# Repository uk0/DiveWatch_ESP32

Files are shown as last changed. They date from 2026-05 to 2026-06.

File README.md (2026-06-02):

<p align="center">
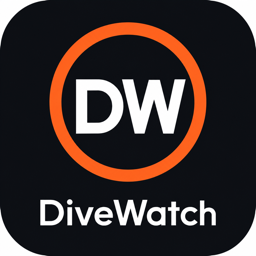
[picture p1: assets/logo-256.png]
DiveWatch
  
</p>

<h1 align="center">DiveWatch</h1>

<p align="center">
  <b>DIY 开源潜水电脑</b> · ESP32-S3 + ST7789 + MS5837<br/>
  完整工程：<b>固件 + 3D 外壳 + 安卓 App</b>
</p>

<p align="center">
  <a href="README.md">中文</a> ·
  <a href="README.en.md">English</a> ·
  <a href="LICENSE">MIT License</a>
</p>

<p align="center">
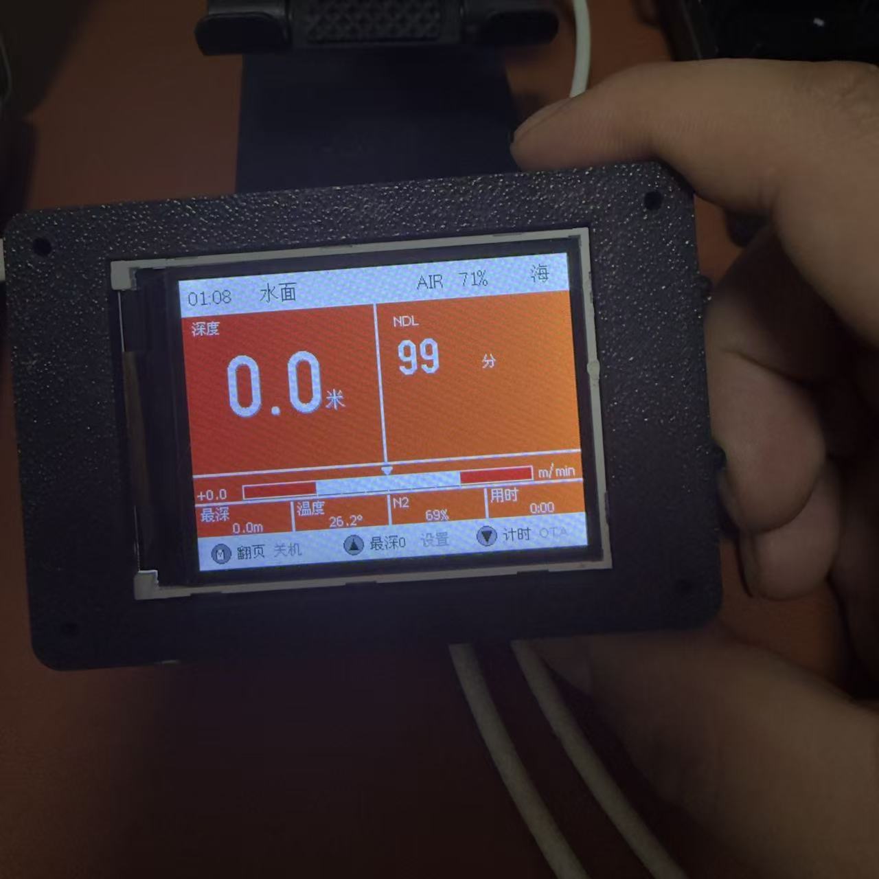
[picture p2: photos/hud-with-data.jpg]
HUD 主页
  
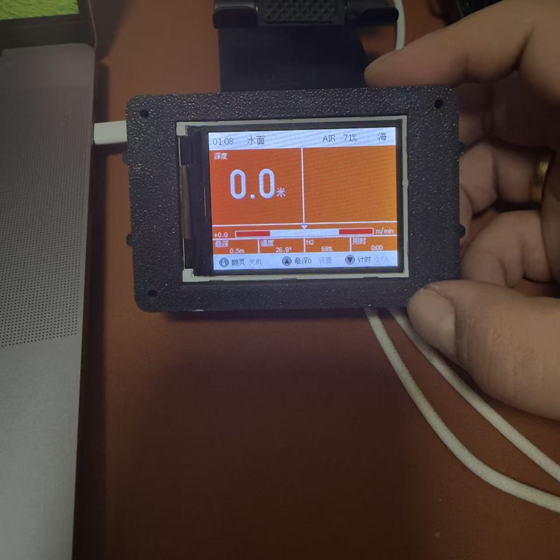
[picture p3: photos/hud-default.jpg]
HUD 默认
  
</p>
<p align="center">
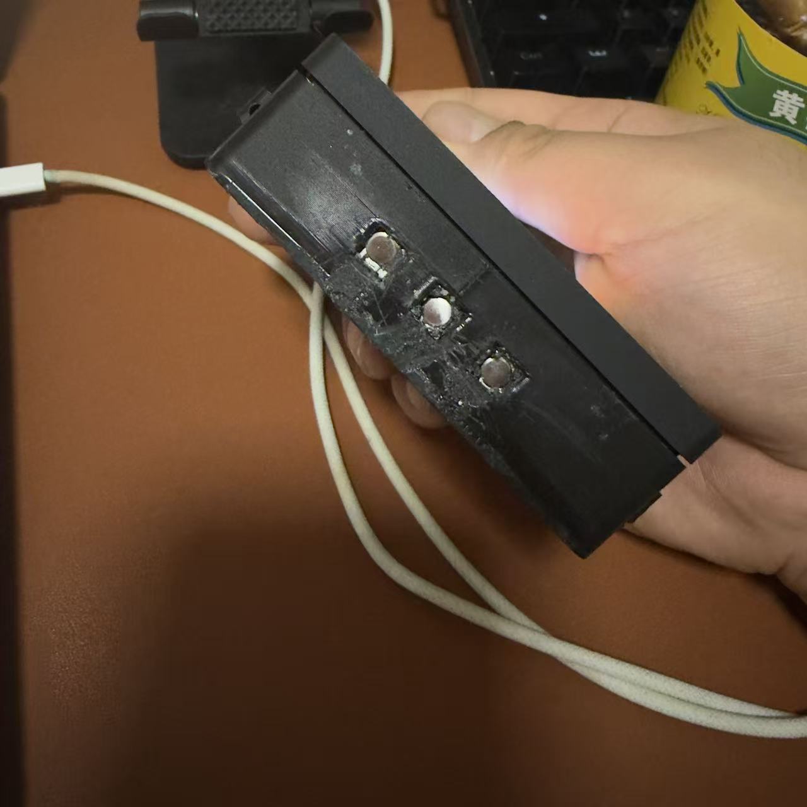
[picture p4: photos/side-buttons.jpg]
3 按钮侧
  
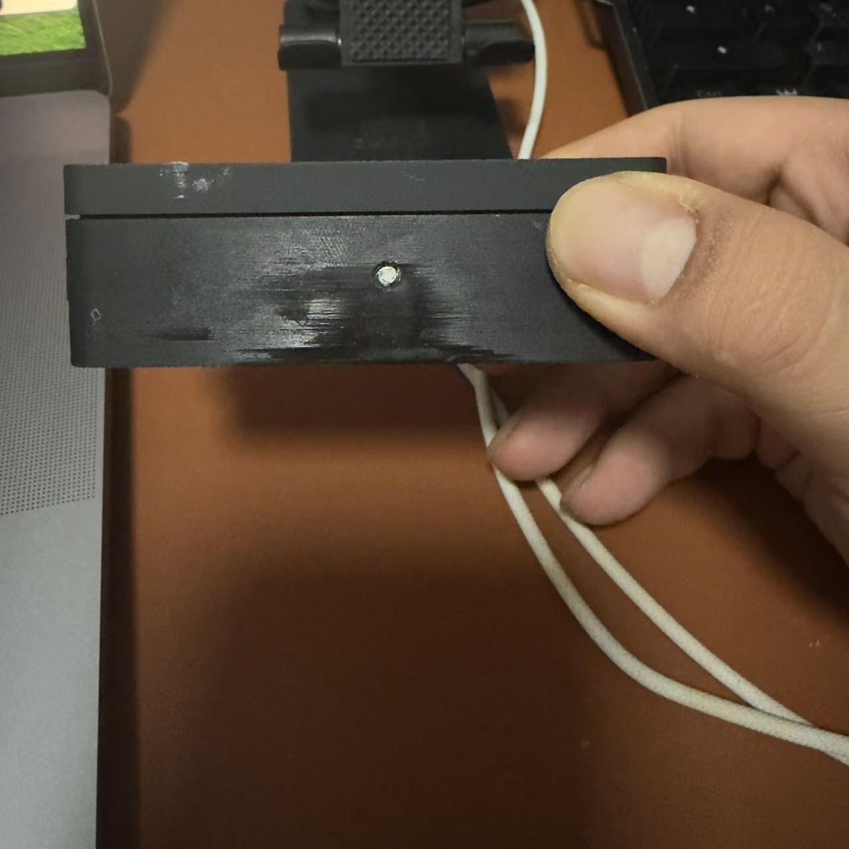
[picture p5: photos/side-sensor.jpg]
压力传感器侧
  
</p>

---

> ⚠ **本项目仅供学习娱乐，未经任何潜水认证机构认证。下水必须携带认证潜水电脑或潜水表作为主设备。**

## 特性

- **Garmin Descent X50i 风格 HUD**：11 个数据页面 + 全屏告警 + 进出水画面
- **ZHL-16C Bühlmann 减压算法**：16 组织室 + 海拔补偿 + 保守因子
- **安全停留 AOW 标准**：2.5-6m 窗口，累积计时，30s 抖动容差
- **OTA 刷不死**：BLE 配 WiFi → WiFi OTA 双 slot 自动回滚
- **超低功耗待机**：Light Sleep ~5mA / Deep Sleep ~10μA
- **完整 3D 打印外壳**：树脂底壳 + 树脂顶盖 + TPU 软套
- **Android App**：扁平化 BLE 配 WiFi + WiFi OTA + 潜水记录本地存储

## 仓库结构

```
watcher/
├── arduino/DiveWatch_v4/    # 固件 (~3400 行 .ino + BLE OTA 模块)
├── case_v5/                 # 3D 外壳源码 (build123d Python)
├── case/                    # 3D 外壳产物 (.step / .stl / .3mf)
├── android_app/             # 安卓 App (Capacitor 7 + Vanilla JS)
├── assets/                  # 图片资源
├── PINOUT.md                # ESP32-S3 引脚映射
├── HARDWARE.md              # BOM + 接线图
└── README.md / README.en.md
```

## 硬件

| 件 | 型号 | 接线 |
|---|---|---|
| 主控 | ESP32-S3-Nano (4 MB Flash / 8 MB PSRAM) | — |
| 显示屏 | ST7789 2.4" SPI 240×320 | CS=21 / DC=18 / RST=17 / MOSI=38 / SCK=48 / BL=8 |
| 压力传感器 | MS5837-30BA | I²C SDA=11 / SCL=12 (地址 0x76) |
| 按键 | 3 × 6×6 SMT | MODE=6 / UP=7 / DOWN=10 |
| 蜂鸣器 | 9042 + S8050 NPN | GPIO 5 经 1kΩ → 三极管基极 |
| 电池监测 | 2:1 分压 (推荐 10K+10K) | ADC A0 = GPIO 1 |
| 无线充电 | Qi 5V/1A 接收 + TP4056 | 详见 [HARDWARE.md](HARDWARE.md) |

完整引脚清单 → [PINOUT.md](PINOUT.md) · BOM/接线图 → [HARDWARE.md](HARDWARE.md)

## 快速开始

### 1. 固件烧录

```bash
cd arduino
arduino-cli compile --upload \
  -p /dev/cu.usbmodem2101 \
  --fqbn esp32:esp32:esp32s3:PartitionScheme=min_spiffs,CDCOnBoot=cdc \
  DiveWatch_v4
```

第一次烧入需要 BOOT+RST 进下载模式。后续可通过 OTA 升级（无需 USB）。

### 2. 3D 打印外壳

```bash
cd case_v5
pip install build123d
python3 case_v5.py
# 输出: ../case/{top_cover, bottom_case, tpu_bumper}.{step, stl, 3mf}
```

| 件 | 工艺 | 推荐材料 |
|---|---|---|
| `bottom_case` | 树脂 (SLA/DLP) | 高韧性灰树脂, 层高 0.05mm |
| `top_cover` | 树脂 (SLA/DLP) | 同上，屏幕窗精度要求高 |
| `tpu_bumper`  | FDM | TPU 95A，0.2mm 层高，30mm/s |

### 3. Android App 编译

```bash
cd android_app
npm install
npm run build           # esbuild bundle
npx cap sync android
JAVA_HOME=/Library/Java/JavaVirtualMachines/temurin-25.jdk/Contents/Home \
  ./android/gradlew -p ./android assembleDebug
# APK 输出: android/app/build/outputs/apk/debug/app-debug.apk
```

## OTA 升级流程

**第一次配 WiFi (BLE)**

1. 设备进 OTA 模式：设置菜单 → 第 14 项「进入 OTA」
2. 手机 App → 工具页 → 扫描连接 `DiveWatch-OTA`
3. WiFi 配置卡填 SSID + 密码 → 点连接
4. 设备屏幕显示分配的 IP

**后续升级 (WiFi)**

1. 设备进 OTA 模式（自动连之前保存的 WiFi）
2. App 工具页 → 固件 OTA → 选 .bin 文件 → 推送
3. 进度条 100% 设备自动重启
4. **5 秒内未启动成功，自动回滚到上一版本**

完整 OTA 说明 → [arduino/DiveWatch_v4/OTA_GUIDE.md](arduino/DiveWatch_v4/OTA_GUIDE.md)

## 屏幕布局

```
┌─顶栏: 时间│DIVE/水面│AIR│电量│海/淡────┐  黑底白字
├─[2px 黑]──────────────────────────────┤
│ 深度        │  NDL / 安停 / 上升过快  │  橙底
│ XX.X 米     │  XX (大字)              │
│ ▼最深 X.Xm │  状态/动作               │
├─[2px 黑]──────────────────────────────┤
│ +X.X ◀━━━●━━━▶ m/min                  │  上升速度
├─[2px 黑]──────────────────────────────┤
│最深│温度│N2│用时                       │  数据条
├─[2px 黑]──────────────────────────────┤
│ ⓂM翻页│ ▼最深0│ ▲计时                 │  黑底白字按键提示
└─────────────────────────────────────────┘
```

## 11 个页面

| 页 | 内容 |
|---|---|
| HUD | 主页面 (深度/NDL/安停/速度/温度/用时/N2/最深) |
| PROFILE | 潜水深度曲线 |
| TISSUE | 16 组织室饱和度条 |
| N2 | 当前 N2 负载详情 |
| PLAN | 下潜计划 (NDL 表) |
| AIR | 气瓶 SPG + SAC + Air Time |
| TEMP | 温度趋势 |
| BAT | 电池电压/百分比/曲线 |
| LASTDIVE  | 上次潜水摘要 |
| LOG | 潜水日志列表 |
| STATS | 累计统计 |

## 文档

- [PINOUT.md](PINOUT.md) — ESP32-S3 引脚完整映射
- [HARDWARE.md](HARDWARE.md) — BOM + 接线图 + 装配顺序
- [arduino/DiveWatch_v4/OTA_GUIDE.md](arduino/DiveWatch_v4/OTA_GUIDE.md) — OTA 防砖架构
- [android_app/README.md](android_app/README.md) — App 开发说明
- [CHANGELOG.md](CHANGELOG.md) — 版本历史
- [CONTRIBUTING.md](CONTRIBUTING.md) — 贡献指南

## 许可证

MIT — 见 [LICENSE](LICENSE)。

## 致谢

- [build123d](https://github.com/gumyr/build123d) — Python CAD
- [u8g2](https://github.com/olikraus/u8g2) — 字体引擎
- [NimBLE-Arduino](https://github.com/h2zero/NimBLE-Arduino) — 轻量 BLE 栈
- [Adafruit GFX / ST7789](https://github.com/adafruit/Adafruit-GFX-Library) — 显示驱动
- [Capacitor](https://capacitorjs.com/) — Web → 原生 App 框架
- [Chart.js](https://www.chartjs.org/) — 图表
- Bühlmann ZHL-16C 减压算法参考 [Shearwater](https://www.shearwater.com/) 公开文档

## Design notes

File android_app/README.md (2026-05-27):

# DiveWatch Android App

Capacitor 7 + Vanilla JS + Chart.js + IndexedDB

## 功能

- **主页**: 大字电池 + 深度/温度/WiFi/IP 四宫格 + 深度实时曲线 + 累计统计
- **日志**: 历次潜水柱状图 + 列表（自动按 60s 静止判定潜水结束并落库）
- **工具**: BLE 扫描连接 / WiFi 配置 / WiFi OTA 推送 / 实时日志

## 存储

- 设置项 (WiFi SSID): `@capacitor/preferences`
- 潜水记录: IndexedDB (database `divewatch`, store `dives`)

## BLE

走 `@capacitor-community/bluetooth-le` 原生插件，Android 12+ 自动请求 BLUETOOTH_SCAN/CONNECT 权限。
浏览器开发时回退 Web Bluetooth。

## 构建

```bash
cd android_app
npm install
npm run build        # esbuild bundle www/app.js → www/bundle.js
npm run sync         # cap sync android (拷贝 www → android/app/src/main/assets/public)

# build APK (debug)
JAVA_HOME=/Library/Java/JavaVirtualMachines/temurin-25.jdk/Contents/Home \
  ./android/gradlew -p ./android assembleDebug

# 出 APK 路径
ls android/app/build/outputs/apk/debug/app-debug.apk
```

## Logo

由 gpt-image-2 生成 (`icon.png`)，已切成 5 档 mipmap 放入 `android/app/src/main/res/mipmap-*`.

## 安装到手机

1. 用 USB 把 `app-debug.apk` 拷到手机 (或 adb install)
2. 手机开 "未知来源安装" 权限
3. 双击 APK 安装
4. 打开 App → 工具页 → 扫描连接 (DiveWatch-OTA)

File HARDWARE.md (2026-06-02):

# DiveWatch 硬件清单

## BOM (Bill of Materials)

### 主板

| 件 | 型号 | 数量 | 参考价 (¥) | 备注 |
|---|---|---|---|---|
| 主控板 | ESP32-S3-Nano | 1 | 25-40 | 4MB Flash / 8MB PSRAM, Arduino Nano 形态 |
| 显示屏 | ST7789 2.4" SPI 240×320 | 1 | 25-35 | 必须带 FPC 排线 |
| 压力传感器 | MS5837-30BA | 1 | 40-60 | I²C 0x76, 30 bar 量程 |
| 按键 | 6×6 SMT 微动开关 | 3 | 0.5/颗 | 6.2mm 帽 |
| 蜂鸣器 | 9042 无源 | 1 | 2 | 5V 驱动 |
| NPN 三极管 | S8050 | 1 | 0.2 | 蜂鸣器开关 |
| 限流电阻 | 1kΩ 0805 | 1 | 0.1 | 基极电流限制 |

### 电池 & 充电

| 件 | 型号 | 数量 | 参考价 (¥) | 备注 |
|---|---|---|---|---|
| 锂电池 | 503040 600mAh Li-Po | 1 | 8-15 | 单体 3.7V |
| 充电管理 | TP4056 USB-C 带保护板 | 1 | 3-5 | 1A 充电, DW01 过冲过放保护 |
| 无线充接收 | Qi 5V/1A 模块带 43mm 线圈 | 1 | 10-15 | 直径需匹配 45mm 凹槽 |
| 电池分压电阻 | 10kΩ × 2 (0805) | 2 | 0.1 | ADC 友好, 漏电 210μA |
| 充电底座 | 任意 Qi 5W 充电板 | 1 | 30-80 | Anker / 小米 / 绿联 |

### 外壳 & 配件

| 件 | 规格 | 数量 | 参考价 (¥) | 备注 |
|---|---|---|---|---|
| 树脂打印 (底壳) | bottom_case.3mf 21mm | 1 | 15-30 | 8K 树脂打印推荐 |
| 树脂打印 (顶盖) | top_cover.3mf 7mm | 1 | 10-20 | 同上 |
| TPU 软套 | tpu_bumper.3mf | 1 | 5-10 | TPU 95A FDM 自打 |
| M2 自攻螺丝 | 8mm 长 4 颗 | 4 | 0.2 | 装顶盖 |
| 弹簧棒 | 24mm × Φ2.5 | 2 | 1 | 接表带 |
| 表带 | 24mm 宽硅胶 | 1 | 10-30 | 任意运动手表表带 |
| 防水 O 圈 | 自定义剪 | 1 | 1 | 密封槽 (可选, 已有 lip 设计) |

**总成本估算：¥150-300** (含一套 3D 打印外壳)

## 接线图

```
                     ┌───────────────┐
                     │  ESP32-S3-Nano │
                     │               │
   ST7789 ─SPI─────►│ GPIO 21 (CS)  │
                    │ GPIO 18 (DC)  │
                    │ GPIO 17 (RST) │
                    │ GPIO 38 (MOSI)│
                    │ GPIO 48 (SCK) │
                    │ GPIO  8 (BL)  │
                    │               │
   MS5837 ─I²C─────►│ GPIO 11 (SDA) │
                    │ GPIO 12 (SCL) │
                    │               │
   按键 ────────────►│ GPIO  6 (MODE)│
                    │ GPIO  7 (UP)  │
                    │ GPIO 10 (DOWN)│
                    │               │
   蜂鸣器 ─1kΩ─B─NPN─│ GPIO  5       │
                    │               │
   电池+ ──[10K]────►│ GPIO  1 (ADC) │
            │       │               │
           [10K]    │ 3V3 / GND     │
            │       └───────────────┘
           GND
                    ┌───────────────┐
   Qi RX 5V+ ──────►│  TP4056 IN+   │
                    │  TP4056 IN-   │── GND
   ┌────────────────│  TP4056 BAT+  │
   │                │  TP4056 BAT-  │── GND
   │
   ▼ 电池 +
   Li-Po 600mAh
   ▼ 电池 -
   GND
```

## 引脚总览

完整引脚映射见 [PINOUT.md](PINOUT.md)。

| 类别 | 引脚 |
|---|---|
| 已用 | 1, 5, 6, 7, 8, 10, 11, 12, 17, 18, 21, 38, 48 |
| 空闲 | 2, 3, 4, 9, 13, 14, 43, 44, 47 |
| 占用 (USB/Flash/PSRAM) | 0, 15, 16, 19, 20, 26-37, 39-42, 45, 46 |

## 装配顺序

1. **PCB 焊接** — 主控、屏幕排线、按键、蜂鸣器电路、电池分压
2. **底壳准备** — 检查内腔尺寸，按键孔通畅
3. **无线充线圈** — 双面胶固定到底壳内腔顶 (Qi 线圈凹槽)
4. **电池** — 放入内腔底部
5. **TP4056** — 焊好后用 Kapton 胶带固定到电池上方
6. **主控板** — 屏幕从顶盖底部装入（4 凸起卡 PCB），FPC 折弯进 PCB 沉槽
7. **盖上顶盖** — 对齐密封槽 + 凸起
8. **4 颗 M2 螺丝** — 拧紧固定
9. **TPU 套** — 拉伸套入，按键孔/传感器孔/屏幕窗/表带通道全对齐
10. **接表带** — 弹簧棒压入耳片孔

## 防水建议

- 密封 lip + 槽设计已提供 IP55 级 (浅水）
- 真要下深水：
  - 密封槽涂硅胶脂 (Permatex Dielectric Grease)
  - 增加丁腈 O 圈
  - 螺丝头部涂厌氧胶
  - **务必做压力测试**：泡 30 分钟 -10m 深度等效气压（约 2 bar）

⚠ DIY 防水极不可靠，**严禁下任何超出泳池深度的水**。

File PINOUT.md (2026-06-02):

# DiveWatch v4 引脚总表 (ESP32-S3-Nano)

## 一、开发板信息

| 项目 | 值 |
|---|---|
| 主控芯片 | ESP32-S3 (双核 240MHz, 4MB Flash, 8MB PSRAM) |
| 开发板名称 | ESP32-S3-Nano (Arduino Nano 形态) |
| 板载接口 | USB-C (兼容 OTG + CDC) |
| 工作电压 | 3.3V |
| 板载稳压 | 5V → 3.3V LDO |
| 引脚数 | 30 (左右各 15) |
| 通讯接口 | UART × 1, I²C × 1, SPI × 1, USB-CDC × 1 |
| ADC | 12-bit, 多通道 (GPIO 1-10 可作 ADC) |
| Arduino-ESP32 核心 | 3.3.8 |
| FQBN | `esp32:esp32:esp32s3:PartitionScheme=min_spiffs,CDCOnBoot=cdc` |
| 分区方案 | min_spiffs (1.94MB × 2 OTA slot + 128KB SPIFFS) |
| Sketch 大小 | ~1.84 MB (占 93% 单 slot) |
| RAM 使用 | ~80 KB |
| 烧录波特率 | 921600 baud |

### CPU 频率档位 (代码 130-131 行)

| 状态 | 频率 | 估计电流 |
|---|---|---|
| 活动工作 (CPU_FREQ_ACTIVE) | 240 MHz | ~80 mA |
| 屏保 (CPU_FREQ_IDLE) | 80 MHz | ~40 mA |
| Light Sleep | ~ | ~5-10 mA |
| Deep Sleep | ~ | ~10 μA |

---

## 二、引脚分配总表

### 显示器 ST7789 2.4" SPI (HSPI 总线, 40 MHz)

| 信号 | GPIO | 板上丝印 | 用途 |
|---|---|---|---|
| **TFT_CS** | **GPIO 21** | D10 | SPI 片选 |
| **TFT_DC** | **GPIO 18** | D9  | Data/Command 切换 |
| **TFT_RST** | **GPIO 17** | D8  | 硬复位 |
| **TFT_MOSI** | **GPIO 38** | D11 | SPI 主出从入 (HSPI MOSI) |
| **TFT_SCK** | **GPIO 48** | D13 | SPI 时钟 (HSPI SCK) |
| (TFT_MISO) | — | — | 未连接 (显示器单向只写) |
| **BLK 背光** | 3V3 | — | 接 3V3 永亮 (软件无控制) |
| VCC | 3V3 | — | 显示器电源 |
| GND | GND | — | 共地 |

### MS5837-30BA 压力传感器 (I²C, 400 kHz)

| 信号 | GPIO | 板上丝印 | 用途 |
|---|---|---|---|
| **I2C_SDA** | **GPIO 11** | D2 | I²C 数据 |
| **I2C_SCL** | **GPIO 12** | D3 | I²C 时钟 |
| VIN | 3V3 | — | 传感器电源 |
| GND | GND | — | 共地 |
| 100nF 电容 | VIN↔GND | — | 退耦 (必须) |

**I²C 地址**: `0x76` (MS5837-30BA 固定地址)

### 按钮 (内部上拉, 按下短接 GND)

| 信号 | GPIO | 板上丝印 | 用途 |
|---|---|---|---|
| **BTN_MODE_PIN** | **GPIO 6** | D4 | 模式键 (翻页 / 长按关机) |
| **BTN_UP_PIN** | **GPIO 7** | D5 | 上键 (最深0 / 设置增) |
| **BTN_DOWN_PIN** | **GPIO 10** | D7 | 下键 (计时重置 / 设置减) |

**按键时序**: 30ms 防抖 + 1200ms 长按阈值 + 5s 关机阈值。

### 蜂鸣器 (有源, 经 S8050 NPN 驱动)

| 信号 | GPIO | 板上丝印 | 用途 |
|---|---|---|---|
| **BUZZER_PIN** | **GPIO 5** | D1 | NPN 基极 (1kΩ 限流) |

**驱动电路**: GPIO 5 → 1kΩ → S8050 Base; Emitter→GND; Collector→蜂鸣器−; 蜂鸣器+ → 3V3。

### 电池电压检测 (ADC 分压)

| 信号 | GPIO | 板上丝印 | 用途 |
|---|---|---|---|
| **BAT_ADC_PIN** | **GPIO 1** | A0 | 电池电压 ADC (2:1 分压) |

**分压电路**: 电池 + → 4.7kΩ → ADC 引脚 → 4.7kΩ → GND。  
**软件校准系数** `g_batDivider = 2.10` (适配 ±5% 电阻容差, 可在设置菜单微调 1.80-2.30)。

### USB-C (板载, 自动复用)

| 信号 | 用途 |
|---|---|
| USB-C 5V | 充电 + 通讯 (经 TP4056 充电保护板) |
| USB D+/D− | USB CDC 串口 (CDCOnBoot=cdc 启用) |

---

## 三、未使用引脚 (可扩展)

下列引脚目前空闲，可用于未来扩展（磁力计/加速度计/外置 Flash 等）：

| GPIO | 板上丝印 | 推荐用途 |
|---|---|---|
| GPIO 2 | A1 | 备用 ADC |
| GPIO 3 | A2 | 备用 ADC / 触摸 |
| GPIO 4 | A3 | 备用 ADC / 触摸 |
| GPIO 8 | A4 | 备用 (磁力计 INT) |
| GPIO 9 | A5 | 备用 |
| GPIO 13 | A6 | 备用 |
| GPIO 14 | D6 | 备用 |
| GPIO 15 | — | 备用 |
| GPIO 16 | — | 备用 |
| GPIO 33-37 | — | PSRAM 用 (不能动) |
| GPIO 39-42 | — | 备用 |
| GPIO 45-47 | — | 备用 |

⚠️ **不能使用**：GPIO 19/20 (USB D+/D−), GPIO 0 (Boot 控制), GPIO 22-32 (内部 Flash/PSRAM)

---

## 四、外围模块 BOM

| 模块 | 型号 | 数量 | 接线引脚 |
|---|---|---|---|
| 主控板 | ESP32-S3-Nano (R8, 8MB Flash + 8MB PSRAM) | 1 | — |
| 显示模块 | ST7789 2.4" SPI 240×320 | 1 | GPIO 17/18/21/38/48 + 3V3/GND |
| 压力传感器 | MS5837-30BA | 1 | GPIO 11/12 + 3V3/GND |
| 蜂鸣器 | 9042 有源蜂鸣器 (3-5V) | 1 | GPIO 5 (经 NPN) |
| NPN 三极管 | S8050 | 1 | 驱动蜂鸣器 |
| 限流电阻 | 1 kΩ (棕黑红金) | 1 | S8050 Base |
| 分压电阻 | 4.7 kΩ ×2 | 2 | ADC 分压 |
| 充电板 | TP4056 + DW01 + FS8205 (带保护) | 1 | USB-C + 电池 |
| 锂电池 | 3.7V 850 mAh (50×30×5 mm) | 1 | TP4056 B+ / B− |
| 退耦电容 | 100 nF (104) | 1 | MS5837 VIN-GND |
| 按钮 | 4 脚扁平微动按钮 | 3 | GPIO 6/7/10 |

---

## 五、走线建议 (飞线方案)

```
ESP32-S3-Nano        外设
─────────────────────────────────
D2 (GPIO11) ──I2C── SDA  MS5837
D3 (GPIO12) ──I2C── SCL  MS5837
3V3        ──────── VIN  MS5837 (+ 100nF 退耦)
GND        ──────── GND  MS5837

D8 (GPIO17) ─SPI─── RST  ST7789
D9 (GPIO18) ─SPI─── DC   ST7789
D10(GPIO21) ─SPI─── CS   ST7789
D11(GPIO38) ─SPI─── SDA  ST7789 (MOSI)
D13(GPIO48) ─SPI─── SCL  ST7789 (SCK)
3V3        ──────── VCC + BLK
GND        ──────── GND

D1 (GPIO5)  ──1kΩ── Base S8050
GND        ──────── Emitter
                    Collector ── 蜂鸣器(−)
3V3        ──────── 蜂鸣器(+)

D4 (GPIO6)  ──────── 按钮 MODE ─── GND
D5 (GPIO7)  ──────── 按钮 UP   ─── GND
D7 (GPIO10) ──────── 按钮 DOWN ─── GND

A0 (GPIO1)  ─4.7k── 电池 BAT+
                   ─4.7k── GND  (分压中点)

TP4056:
  IN+/IN−  ──── USB-C
  B+/B−    ──── 电池
  OUT+     ──── ESP32-S3 5V (经板载稳压 → 3V3)
  OUT−     ──── GND
```

---

## 六、烧录命令

```bash
# 编译
arduino-cli compile \
  --fqbn esp32:esp32:esp32s3:PartitionScheme=huge_app,CDCOnBoot=cdc \
  arduino/DiveWatch_v4

# 烧录
arduino-cli upload \
  -p /dev/cu.usbmodem2101 \
  --fqbn esp32:esp32:esp32s3:PartitionScheme=huge_app,CDCOnBoot=cdc \
  arduino/DiveWatch_v4
```

⚠️ 首次烧录前需手动进入下载模式：**按住 BOOT + 短按 RST → 松开 RST → 松开 BOOT**。  
`CDCOnBoot=cdc` 启用后第二次起 esptool 自动 reset 进入下载模式。

---

## 七、功耗估算

| 场景 | 电流 | 850mAh 续航 |
|---|---|---|
| HUD 主屏运行 (240MHz, 屏幕亮) | ~120 mA | ~7 h |
| 屏保 + Light Sleep (80MHz, 屏幕仍亮) | ~50 mA | ~17 h |
| 屏保 + Light Sleep + 屏幕关 (理论) | ~10 mA | ~85 h |
| Deep Sleep (RTC 唤醒) | ~10 μA | 数年 |

⚠️ 当前 BLK 接 3V3 永亮，背光占主要功耗（~25 mA）。如需省电，可把 BLK 改接 GPIO 做 PWM 调光（**PINOUT 升级方案**）。

---

## 八、引脚定义索引 (代码位置)

| 定义 | 文件 | 行号 |
|---|---|---|
| TFT_CS / DC / RST / MOSI / SCK | DiveWatch_v4.ino | 38-42 |
| I2C_SDA / I2C_SCL | DiveWatch_v4.ino | 106-107 |
| BUZZER_PIN | DiveWatch_v4.ino | 108 |
| BTN_MODE_PIN / BTN_UP_PIN / BTN_DOWN_PIN | DiveWatch_v4.ino | 109-111 |
| BAT_ADC_PIN | DiveWatch_v4.ino | 112 |
| WIFI_SSID / NTP 服务器 | DiveWatch_v4.ino | 73-77 |
| CPU 频率档位 | DiveWatch_v4.ino | 129-130 |

如改动接线，只需改这些 `#define`，无需动其他代码。

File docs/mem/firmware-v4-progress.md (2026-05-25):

# DiveWatch v4 固件开发进度快照 (2026-05-26)

## 当前固件版本
- 主目录: `arduino/DiveWatch_v4/`
- 文件:
  - `DiveWatch_v4.ino` (主固件, ~3400 行)
  - `ota_ble.ino` (BLE + WiFi OTA 模块)
  - `partitions.csv` (已删, 改用预设 `min_spiffs`)
  - `OTA_GUIDE.md` (OTA 使用文档)
  - `ota_web_client.html` (浏览器 BLE 配 WiFi 工具)

## 编译/烧录命令
```bash
# 编译 + USB 烧录
arduino-cli compile --upload \
  -p /dev/cu.usbmodem2101 \
  --fqbn esp32:esp32:esp32s3:PartitionScheme=min_spiffs,CDCOnBoot=cdc \
  DiveWatch_v4

# WiFi OTA (浏览器访问 http://<IP>/ 上传 .bin)
# 在 OTA 模式下设备显示 IP, 浏览器打开即可
```

## 硬件
- ESP32-S3-Nano (4MB Flash, 8MB PSRAM)
- ST7789 2.4 寸 SPI 屏 240x320 (HSPI 40MHz)
- MS5837-30BA 压力传感器 (I2C 0x76)
- 3 按钮 (GPIO 6/7/10) + 蜂鸣器 (GPIO 5) + 电池 ADC (GPIO 1)
- 4MB Flash 限制下 sketch ~1.84MB, min_spiffs 双 OTA slot 1.96MB 各

## 已实现功能
1. **Garmin Descent X50i 风格 UI**: 11 个页面 (HUD/PROFILE/TISSUE/N2/PLAN/AIR/TEMP/BAT/LASTDIVE/LOG/STATS) + 设置 + 时间编辑 + 屏保 + 全屏告警
2. **ZHL-16C Bühlmann 减压算法** + 16 组织室 + 海拔补偿 + 保守因子
3. **安全停留 AOW 标准** (2.5-6m 窗口, 累积计时, 30s 抖动容差)
4. **TTS + Ceiling 计算** (上升到水面时间, 含减压停留)
5. **气瓶 SPG**: 初始 bar / 瓶容 / SAC / Air Time 估算
6. **进出水画面**: 进入 1.5s "GO!", 退出 5s 总结
7. **WiFi NTP 校时** (用户填 SSID/PSK)
8. **Light sleep + Deep sleep** 省电
9. **配色**: 橙底 + 黑文字 + 红警告 (Shearwater 水下哲学)
10. **OTA 防砖**: BLE 配 WiFi → WiFi OTA / HTTP Web 上传 / 双 slot 自动回滚

## OTA 防砖架构
- **双 OTA 分区** (min_spiffs: 1.94MB×2 + 128KB SPIFFS)
- **触发方式** (4 种):
  - 设置菜单 → 第 14 项「进入 OTA」→ UP/DOWN 确认
  - 长按 UP 5 秒 / DOWN 5 秒
  - 串口发 `OTA\n`
  - 开机时按 UP **或** DOWN (救援模式, 跳过所有初始化)
- **退出 OTA**: MODE 双击 (400ms 内 2 次) / 长按 1 秒
- **OTA 通道**:
  - HTTP Web (端口 80, 浏览器访问 `http://<IP>/` 上传)
  - ArduinoOTA (端口 3232, `espota.py` 命令行)
  - BLE 配 WiFi (NimBLE-Arduino 2.5.0)
- **自动回滚**: 新固件 5s 内未 `mark_valid` 下次重启回上一 slot

## 屏幕刷新优化
- HUD 渲染 100ms (10Hz)
- 缓存层: time/HH:MM, DIVE 状态, 用时秒, 电量, 海/淡, 大字深度, NDL, 安停, 速度条, 数据条 4 项, AIR (静态)
- 上升速度阈值 0.5 m/min (避免传感器噪声触发重画)

## 已知问题/待办
- 4MB Flash 限制下 sketch 91% 占用, 加新功能需先瘦身
- ArduinoOTA UDP invitation 在某些路由器下不稳, 推荐用 HTTP Web 上传
- 字体合并副作用: wqy13→wqy12 (字号小 1px), logisoso26→24

## 关键文件大小
- DiveWatch_v4.ino: ~3400 行 / ~120 KB
- ota_ble.ino: ~250 行
- 编译产物 .bin: ~1.84 MB

## Git 历史 (最近)
```
7aa8a60 HUD 屏闪深度优化: 用时缓存(1Hz)+AIR静态(0Hz)+上升阈值放宽(0.5m/min)
b840627 OTA + 屏幕刷新优化
24d6283 OTA: 加 HTTP Web 80 端口
ca6908e v4 OTA: BLE 广播显式 name+UUID, TX +9dBm; 长按 MODE 3s 退出 OTA
0b55918 v4 OTA: 加设置菜单第 14 项 '进入 OTA' 避免按键冲突
1d654d3 v4 OTA 双 slot 启用: NimBLE + 字体合并 (sketch 2.06→1.80MB)
```

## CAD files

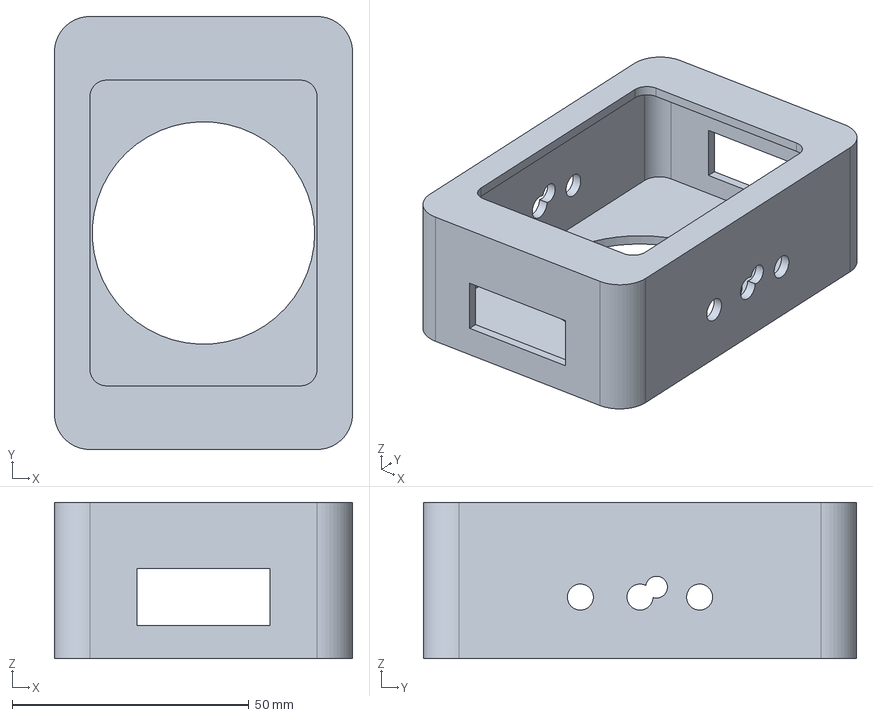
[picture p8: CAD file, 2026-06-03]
case/tpu_bumper.step
63.0 x 91.5 x 33.0 mm

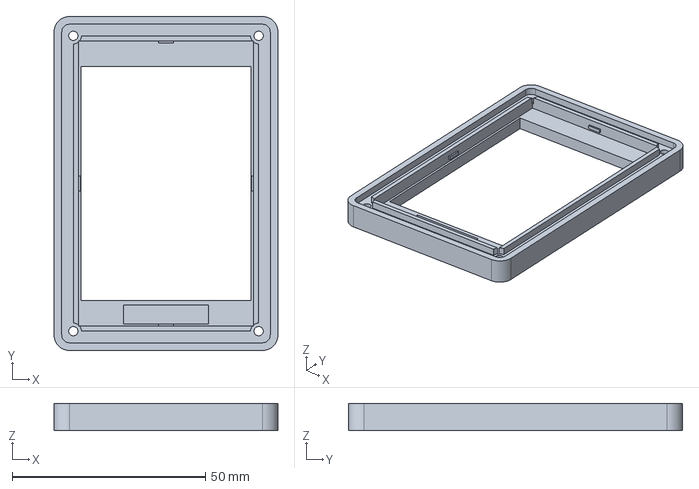
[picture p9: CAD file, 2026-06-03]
case/top_cover.step
58.0 x 86.5 x 7.00 mm

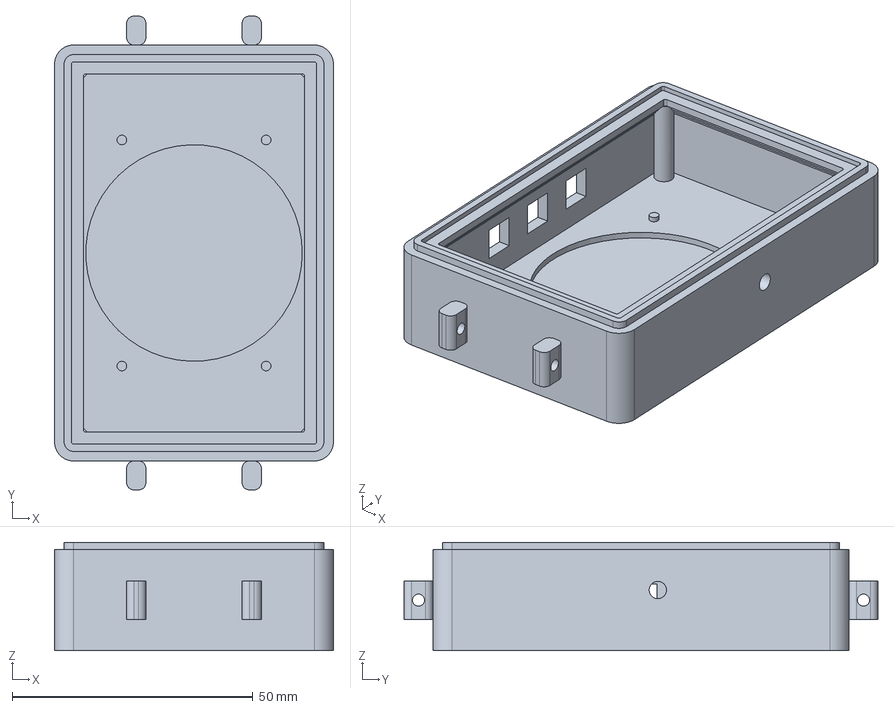
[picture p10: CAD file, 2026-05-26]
case/bottom_case.step
58.0 x 98.5 x 22.5 mm

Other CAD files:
case/bottom_case.3mf
case/bottom_case.stl
case/top_cover.3mf
case/top_cover.stl
case/tpu_bumper.3mf
case/tpu_bumper.stl

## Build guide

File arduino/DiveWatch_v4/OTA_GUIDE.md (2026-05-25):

# 刷不死方案: BLE 配 WiFi + WiFi OTA

## 架构

```
   ┌──────────┐      BLE (慢, 仅控制)        ┌────────────────┐
   │ 用户手机/ │ ─── SSID/PSK + CMD ────→    │  DiveWatch     │
   │ 浏览器    │                              │  ESP32-S3      │
   └──────────┘                              └────────────────┘
        ↓                                            ↓
        │                                       WiFi STA 模式
        │                                            ↓
        │                                     ArduinoOTA :3232
        │                                            ↑
        ↓ 通过家里 WiFi 路由器                       │
   ┌──────────┐    WiFi (快 ~500 KB/s)       ┌─────┴────────┐
   │ PC / 笔记本│ ────── 推 .bin 固件 ──→     │  ESP32-S3    │
   └──────────┘                              └──────────────┘
```

**核心思路**：BLE 只做"配网+控制"（数据量小），WiFi 做"高速传输"（固件 1.9MB / WiFi 4 秒，BLE 200 秒）。

## 三种触发方式

| 方式 | 操作 | 适用 |
|---|---|---|
| **A** | 长按 MODE+UP 3 秒 | 主固件正常, 想升级 |
| **B** | 开机时按 UP+DOWN (救援) | 主固件 brick |
| **C** | 串口/代码 `otaScheduleNextBoot()` | 远程/脚本触发 |

## 一次性首烧 (后面不再需要 USB)

```bash
# 编译 (使用自定义双 OTA 分区)
cd arduino
arduino-cli compile \
  --fqbn esp32:esp32:esp32s3:PartitionScheme=custom,CDCOnBoot=cdc \
  --build-property "build.custom_partitions=partitions" \
  DiveWatch_v4

# 按 BOOT+RST 进下载模式, 然后:
arduino-cli upload \
  -p /dev/cu.usbmodem2101 \
  --fqbn esp32:esp32:esp32s3:PartitionScheme=custom,CDCOnBoot=cdc \
  --build-property "build.custom_partitions=partitions" \
  DiveWatch_v4
```

## 日常 OTA 升级流程

### 第一次配 WiFi (BLE)

1. 设备进 OTA 模式 (任一触发方式)
2. 屏幕显示 "OTA 模式 / BLE 配 WiFi 中..."
3. 手机/电脑用 Chrome/Edge 打开 `ota_web_client.html`
4. 点 "连接 DiveWatch-OTA"
5. 填 WiFi 名 + 密码 → 点 "连接 WiFi"
6. 设备屏幕显示 "OTA 已就绪 / IP: 192.168.x.x"
7. 凭据自动保存到 NVS

### 后续 OTA (WiFi 自动连)

1. 设备进 OTA 模式 (任一方式)
2. **自动用保存的 WiFi 凭据连接** (无需 BLE)
3. 屏幕显示 "OTA 已就绪 / IP: ..."
4. 用 PC 推固件:

```bash
# 用 arduino-cli (推荐, 自动找 .bin)
arduino-cli upload -p 192.168.1.50 \
  --fqbn esp32:esp32:esp32s3:PartitionScheme=custom,CDCOnBoot=cdc \
  --build-property "build.custom_partitions=partitions" \
  DiveWatch_v4

# 或 espota.py 直接推 .bin
python3 ~/Library/Arduino15/packages/esp32/hardware/esp32/3.3.8/tools/espota.py \
  -i 192.168.1.50 -p 3232 \
  -f ~/Library/Caches/arduino/sketches/*/DiveWatch_v4.ino.bin

# 或 Arduino IDE: 工具 → 端口 → 选 DiveWatch (192.168.1.50)
```

5. 进度条到 100% 设备自动重启，新固件运行
6. **5 秒内成功启动则标记 valid，否则下次重启自动回滚**

## BLE GATT 协议

| Char | UUID | 操作 | 内容 |
|---|---|---|---|
| Service | `1d14d6ee-fd63-4fa1-bfa4-8f47b42119f0` | - | OTA 服务 |
| SSID | `f7bf3564-fb6d-4e53-88a4-5e37e0326063` | Write | UTF-8 字符串 |
| PSK | `984227f3-34fc-4045-a5d0-2c581f81a153` | Write | UTF-8 字符串 |
| CMD | `0c533cef-d6b0-4ba2-9f08-7d6cea1b3e7e` | Write | 1 字节: `C` 连 WiFi / `F` 忘记 / `R` 重启 |
| STAT | `3b1f9c5e-8a72-4d11-9b3a-7c4e2f1a5d80` | Notify | UTF-8 状态: `WIFI_OK 192.168.x.x` / `OTA_PROGRESS 45` 等 |

## 自动回滚机制

1. 新固件第一次启动后，调用 `otaArmValidTimer()` 注册 5s 计时
2. 5s 后主程序在 loop 中调 `otaMarkValidIfReady()` → 标记当前 slot valid
3. 如果新固件在 5s 内崩溃 / 看门狗复位 / 卡死
4. 下次重启 ESP32 检测到 slot 没标 valid → 自动切回上一个 slot

**实测保护**：即使推了一个完全跑不起来的固件，5s 后断电重启，会自动恢复到上一版本。

## 安全性

- BLE 无加密 (信任内网环境)
- WiFi PSK 用 NVS 存储 (明文, 设备物理接触可读)
- ArduinoOTA 默认无密码 (内网信任), 可改 `ArduinoOTA.setPassword("...")` 加密码

如果要严格安全：
1. ArduinoOTA 加密码
2. BLE 加 GAP 配对
3. NVS 启用 encryption (esp32-encrypted-flash)

## 文件清单

| 文件 | 作用 |
|---|---|
| `partitions.csv` | 双 OTA 分区表 (3MB + 3MB + 2MB SPIFFS) |
| `ota_ble.ino` | BLE 配 WiFi + ArduinoOTA + 救援模式 |
| `DiveWatch_v4.ino` | 主固件 (含 OTA hooks) |
| `ota_web_client.html` | 浏览器 BLE WiFi 配置工具 |
| `OTA_GUIDE.md` | 本文档 |

## 故障排查

| 问题 | 原因 | 解决 |
|---|---|---|
| 屏幕显示 "WIFI_FAIL" | SSID/PSK 错 | BLE 重新配 |
| WiFi 连上但 OTA 推不进 | 防火墙拦 3232 端口 | PC 同一 WiFi, 关防火墙 |
| PC 看不到 OTA 端口 | mDNS 没解析 | 用 IP 直接连 `-p 192.168.x.x` |
| OTA 进度卡住 | WiFi 信号弱 | 靠近路由器 / 用 2.4G 频段 |
| 新固件白屏 | 编译错误/缺库 | 等 5s 断电, 自动回滚 |
| 不知道设备 IP | BLE 失效 / 屏幕坏 | 路由器后台查 `DiveWatch` 主机名 |

## 速度对比

| 方式 | 速度 | 1.9MB 固件耗时 |
|---|---|---|
| USB 921600 baud | 1.2 MB/s | ~15 秒 |
| **WiFi OTA** | **~500 KB/s** | **~4 秒** |
| BLE 5.0 直传 | ~12 KB/s | ~160 秒 |
| BLE 4.2 直传 | ~5 KB/s | ~400 秒 |

WiFi OTA 速度接近 USB，且不需要接线。

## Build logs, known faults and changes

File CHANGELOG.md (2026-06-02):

# 变更日志

## [v1.0] 2026-05 (开源初版)

### 固件 (DiveWatch_v4)

**核心**
- ZHL-16C Bühlmann 16 组织室减压算法 + 海拔补偿 + 保守因子
- 安全停留 AOW 标准 (2.5-6m, 累积计时, 30s 抖动容差)
- TTS + Ceiling 计算
- 进出水自动识别 + 1.5s GO! 进入画面 + 5s 退出总结

**UI**
- 11 页 Garmin Descent X50i 风格 (HUD/PROFILE/TISSUE/N2/PLAN/AIR/TEMP/BAT/LASTDIVE/LOG/STATS)
- HUD 主区左右分屏：左大字深度 + 右动态状态 (NDL/安停/上升过快/下降过快/减压)
- 安停 / 安停完成 绿色，告警红色
- 分隔线 2px 加粗（水下镜面清晰）
- 大字深度阴影描边（模拟 anti-aliasing）
- SPI 27MHz (40 → 27 降速防细线毛刺)
- 屏保 → 唤醒/退出全屏清，无残影

**电源**
- Light Sleep 屏保 ~5-10mA
- Deep Sleep 关机 ~10μA (GPIO hold 锁背光防浮亮)
- 长按 MODE 5s 立即关机 / 屏保后 10 分钟自动关机
- MODE 长按 2s 唤醒
- 屏幕背光 GPIO 8 软控制

**OTA**
- 双 OTA 分区 (min_spiffs 1.94MB × 2 + 128KB SPIFFS)
- BLE 配 WiFi → WiFi OTA 双通道：HTTP /update + ArduinoOTA :3232
- 5s 内未 markValid 自动回滚
- 4 种触发方式 (菜单/长按 UP/DOWN/串口 OTA)

### 3D 外壳 (case_v5)

- 总厚 28mm (bottom 21 + top 7), 58×86.5mm 主体
- top 7mm: 屏幕窗贯穿 + PCB 沉槽 1.5mm + FPC 排线槽 4mm + 4 凸起卡 PCB
- bottom 21mm: 4 层斜坡 ledge 支撑密封 lip + 内腔顶部缩口防悬空打印失败
- 按钮 z 居中 / 间距 12.6mm / 与 PCB SMT 对齐
- 压力传感器孔右上角对齐 PCB
- 表带耳 + 弹簧棒孔
- 无线充凹槽内腔顶 (45mm × 1.3mm 深)
- TPU bumper 63×91.5×33mm 软保护套 (开屏幕窗/充电窗/按钮孔/传感器孔/表带通道)

### Android App (1.0.0)

- Capacitor 7 + Vanilla JS, APK 4.5MB
- 3 tab 扁平化深色 UI (`#0d0f12` + `#ff7a3a`)
- 主页: 电池 hero + 深度/温度/WiFi/IP 四宫格 + 实时深度曲线 (Chart.js)
- 日志: 历次潜水柱状图 + 列表 (IndexedDB, 60s 静止自动落库)
- 工具: BLE 扫描 + WiFi 配置 + WiFi OTA + 实时日志
- gpt-image-2 生成 logo 5 档 mipmap launcher icon
- Capacitor BLE 原生插件 (Android 12+ 自动请求权限)

---

## 历史里程碑

- **2026-05** Android App 上线, TPU bumper 设计
- **2026-05** HUD 左右分屏 + 屏幕 lip + 凸起卡 PCB
- **2026-05** 安停绿色 + 自动 deep sleep + 背光 GPIO 控制
- **2026-05** 案 v5 完整 (按钮间距 / 传感器位置 / ledge 斜坡支撑)
- **2026-05** OTA 双 slot + BLE 配 WiFi 架构
- **2026-05** ZHL-16C 减压算法 + 安停 + 进出水识别
- **2026-05** Garmin 风格 UI 11 页面
- **2026-05** v4 首版固件

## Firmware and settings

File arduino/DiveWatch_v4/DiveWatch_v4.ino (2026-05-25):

// =====================================================================
//  DiveWatch v2.0  -  ESP32-S3-Nano + MS5837-30BA + OLED SH1106 + Buzzer
//
//  Features:
//    - ZHL-16C 16-compartment Buhlmann NDL calculation (air only)
//    - 5m +/- 1m safety stop detection with 3 min timer
//    - Moving-average noise filter on depth/pressure
//    - 3-button UI (MODE/UP/DOWN), short + long press
//    - NVS persistent dive log (last 10 dives)
//    - 4 pages: HUD, Tissue/NDL, Last dive, Log list
//
//  Pin map (Arduino Nano ESP32 board labels):
//    A4 (GPIO 11) = SDA  [shared with OLED]
//    A5 (GPIO 12) = SCL  [shared with OLED]
//    D2 (GPIO  5) = Buzzer (via 1k -> S8050 base)
//    D3 (GPIO  6) = BTN_MODE  (active-low to GND, internal pullup)
//    D4 (GPIO  7) = BTN_UP    (active-low to GND, internal pullup)
//    D7 (GPIO 10) = BTN_DOWN  (active-low to GND, internal pullup)
//
//  Board: ESP32S3 Dev Module
//    USBMode=hwcdc, CDCOnBoot=cdc, FlashSize=8M, PSRAM=opi
// =====================================================================

#include <Wire.h>
#include <SPI.h>
#include <Adafruit_GFX.h>
#include <Adafruit_ST7789.h>
#include <U8g2_for_Adafruit_GFX.h>
#include <Preferences.h>
#include <WiFi.h>
#include <esp_sleep.h>
#include <driver/gpio.h>
#include <math.h>
#include <time.h>
#include <sys/time.h>
#include "MS5837.h"

// ===== ST7789 SPI 引脚 =====
#define TFT_CS    21
#define TFT_DC    18
#define TFT_RST   17
#define TFT_MOSI  38
#define TFT_SCK   48

// ===== RGB565 颜色 (本屏 invertDisplay(true) + swapRB 流程下, hex 已按实际显示色重新映射) =====
// 流程: 源代码值 X -> swapRB(X) -> 写入帧缓冲 Y -> ST7789 反转 -> 屏幕显示 ~Y
// 故 hex 值不是标准 RGB565, 而是 swapRB(~目标像素) 反推所得
#define RGB_ORANGE  0xFD20    // 屏幕显示橙色 ✓ (实测)
#define RGB_BLACK   0x0000    // 屏幕显示黑色 ✓ (实测)
#define RGB_WHITE   0xFFFF    // 屏幕显示白色 ✓ (实测)
#define RGB_RED     0xFFE0    // 屏幕显示红色 (原 0xF800 会显示成黄)
#define RGB_GREEN   0xF81F    // 屏幕显示绿色 (原 0x07E0 会显示成紫红)
#define RGB_BLUE    0x07FF    // 屏幕显示蓝色 (原 0x001F 会显示成浅青)
#define RGB_YELLOW  0xF800    // 屏幕显示黄色 (现在不用, 留宏避免编译错)
#define RGB_CYAN    0x07E0    // 屏幕显示青色 (现在不用)
#define RGB_DARK    0x4208    // 灰色 (R=B 对称, swapRB 不变, 反相后浅灰)

// swap R/B 5-bit (G 6-bit 不变)
inline uint16_t swapRB(uint16_t c) {
  return ((c & 0x001F) << 11) | (c & 0x07E0) | ((c >> 11) & 0x001F);
}
#define C(x) swapRB(x)

// 前向声明 struct (避免 Arduino IDE 自动生成函数原型时找不到)
struct Button;
struct DiveRecord;
void btnPoll(Button &b, uint32_t now);
void saveDiveToNVS(const DiveRecord &rec);

// =====================================================================
// WiFi NTP 校时配置 (用户修改这两行后烧录即可启用)
//   留空字符串 "" 表示禁用 WiFi 校时
// =====================================================================
static const char* WIFI_SSID = "";
static const char* WIFI_PASS = "";
static const long  TZ_OFFSET_SEC = 8 * 3600;  // UTC+8 (中国)
static const char* NTP_SERVER1 = "ntp.aliyun.com";
static const char* NTP_SERVER2 = "ntp.tencent.com";
static const char* NTP_SERVER3 = "pool.ntp.org";

// ================== Forward type declarations =======================
// (Required so Arduino auto-generated function prototypes can reference them)
struct Button {
  uint8_t  pin;
  bool     stable;
  bool     last;
  uint32_t lastChangeMs;
  uint32_t pressedAtMs;
  bool     longFired;
  bool     evShort;
  bool     evLong;
};

struct DiveRecord {
  float    maxDepth;
  uint16_t durationSec;
  float    minTemp;
  uint8_t  saltwater;     // 1 = sea, 0 = fresh
  uint8_t  _pad;
  uint32_t endEpoch;      // Unix time when dive ended (0 = unknown)
  float    batVoltage;    // 潜水结束时的电池电压 (0 = 未记录)
  float    airUsedL;      // 本次潜水消耗气量 (估算)
  float    avgDepth;      // 本次潜水平均深度 m (0 = 未记录)
};

// ================== Pin map ==========================================
#define I2C_SDA       11
#define I2C_SCL       12
#define BUZZER_PIN     5
#define BTN_MODE_PIN   6
#define BTN_UP_PIN     7
#define BTN_DOWN_PIN  10
#define BAT_ADC_PIN    1     // board pin "A0", reads battery via 2:1 divider
#define TFT_BL_PIN     8     // 屏幕背光控制 (Nano D5), HIGH=亮 LOW=灭
#define TFT_BL_ON      HIGH
#define TFT_BL_OFF     LOW

// Voltage divider: BAT+ -[R1]- ADC -[R2]- GND
// 理想情况 R1=R2 时 BAT_DIVIDER = 2.0, 但 ±5% 精度下实际 1.9-2.1
// 该值现在可在设置菜单"电池校准"中微调 (1.80-2.30, 步 0.02)
float g_batDivider = 2.10f;            // 默认 2.10 (大部分场合够用)
static const float BAT_FULL_V   = 4.20f;
static const float BAT_EMPTY_V  = 3.30f;

// ================== 固定常量 (不可调) ================================
static const float    SURFACE_DEPTH       = 0.5f;
static const float    DIVE_START_DEPTH    = 1.2f;
static const float    SAFETY_STOP_DEPTH   = 5.0f;
static const float    SAFETY_STOP_BAND    = 1.5f;
static const uint32_t SAMPLE_MS           = 100;     // 200→100ms 提升 UI 顺滑度
static const uint32_t REARM_BEEP_MS       = 1500;
static const uint8_t  AVG_WINDOW          = 5;
static const uint32_t CPU_FREQ_ACTIVE     = 240;     // MHz, 正常工作
static const uint32_t CPU_FREQ_IDLE       = 80;      // MHz, 屏保时降频省电

// ================== 可调参数 (设置菜单可改, 持久化) ==================
float    g_alarmDepth      = 30.0f;     // 深度报警 m
float    g_ascentLimit     = 9.0f;      // 上升速率警告 m/min
float    g_descentLimit    = 18.0f;     // 下降速率警告 m/min (PADI 标准 18)
uint32_t g_screenOffMs     = 5UL*60*1000;  // 屏保超时 ms
uint16_t g_safetyStopSec   = 180;       // 安全停留时长 s
bool     g_buzzerEnable    = true;      // 蜂鸣器开关
float    g_fluidDensity    = 1029.0f;   // 水密度 (1029 海, 997 淡)
// OW 水肺潜水标准: AL80 铝瓶 = 11.1L * 210bar
// 改用气压表 (SPG) 标准方式: 输入 初始压力(bar) + 瓶容量(L), 内部算总气量
uint16_t g_initialBar      = 210;       // 初始压力 bar (AL80=210, 12L钢瓶=200/232)
uint8_t  g_tankVolL        = 11;        // 瓶容量 L (AL80=11, 12L钢瓶=12, 15L=15)
uint8_t  g_sacLmin         = 18;        // 水面气体消耗速率 L/min (新手休闲)
uint8_t  g_conservatism    = 100;       // ZHL-16C 保守度因子 % (80-120)
uint8_t  g_lowTempC        = 15;        // 低温报警阈值 ℃

// 派生量: 总气量 (L) = 初始压力 * 瓶容量
inline uint16_t totalAirL()  { return (uint16_t)g_initialBar * (uint16_t)g_tankVolL; }
inline float    barFromAirL(float airL) {
  return (g_tankVolL > 0) ? (airL / (float)g_tankVolL) : 0.0f;
}

// 气量监控运行时状态 (不持久化)
float    g_remainingAirL   = 0.0f;      // 当前剩余气量 L (内部用 L 算, 显示转 bar)
float    g_currentSacL     = 0.0f;      // 当前深度下的实际消耗速率 L/min
uint32_t g_lastAirCalcMs   = 0;

// ================== Globals ==========================================
SPIClass mySPI(HSPI);
Adafruit_ST7789 tft = Adafruit_ST7789(&mySPI, TFT_CS, TFT_DC, TFT_RST);
U8G2_FOR_ADAFRUIT_GFX u8g2;
MS5837 sensor;
Preferences prefs;

float    g_surfacePressure = 1013.25f;
float    g_lastDepth       = 0.0f;
float    g_maxDepth        = 0.0f;
uint32_t g_lastSampleMs    = 0;
uint32_t g_lastBeepMs      = 0;
uint32_t g_diveStartMs     = 0;
bool     g_diving          = false;
bool     g_sensorOk        = false;
float    g_temp            = 0.0f;
float    g_pressureRaw     = 0.0f;
float    g_depthRaw        = 0.0f;
float    g_depthSmooth     = 0.0f;
float    g_ascentMpm       = 0.0f;
float    g_batVoltage      = 0.0f;
uint8_t  g_batPct          = 0;
bool     g_batPresent      = false;
uint32_t g_lastBatReadMs   = 0;

// Real-time clock (uses internal RTC, persisted to NVS every minute)
bool     g_editingTime     = false;
uint8_t  g_editField       = 0;       // 0 = HH, 1 = MM
uint8_t  g_editHH          = 12;
uint8_t  g_editMM          = 0;
uint32_t g_lastTimeSaveMs  = 0;

// 平均深度统计 (本次潜水)
double   g_diveDepthSum  = 0.0;     // 累积 (depth * dt_ms)
uint32_t g_diveTimeMs    = 0;       // 累积时间 ms

// NDL 计划器
uint8_t  g_planDepthM    = 18;      // 用户在 PAGE_PLAN 设的计划深度

// Power saving: dim OLED after idle period (g_screenOffMs is configurable)
uint32_t g_lastInteractMs  = 0;
bool     g_screenOff       = false;
bool     g_pageDirty       = true;        // 切页或首次进入, 触发静态部分重绘
bool     g_saverNeedsRedraw = true;        // 进入屏保时强制 saver 重绘 (覆盖旧帧残影)

// Settings menu state
bool     g_inSettings        = false;
uint8_t  g_settingsItem      = 0;
static const uint8_t SETTINGS_COUNT = 14;

// Lifetime stats (separate from per-dive log, also in NVS)
uint32_t g_lifetimeUnderwaterSec = 0;

// Temperature history (1 sample/min, ring buffer of 60 = 1 hour)
static const uint8_t TEMP_HIST_LEN = 60;
float    g_tempHist[TEMP_HIST_LEN] = {0};
uint8_t  g_tempHistIdx   = 0;
uint8_t  g_tempHistCount = 0;
uint32_t g_lastTempSampleMs = 0;

// Battery voltage history (1 sample/hour, ring buffer of 24 = 1 day)
static const uint8_t BAT_HIST_LEN = 24;
float    g_batHist[BAT_HIST_LEN] = {0};
uint8_t  g_batHistIdx   = 0;
uint8_t  g_batHistCount = 0;
uint32_t g_lastBatHistMs = 0;

// ================== Moving-average filter ============================
float    g_pressBuf[AVG_WINDOW] = {0};
uint8_t  g_pressBufIdx          = 0;
bool     g_pressBufFilled       = false;

float pushPressureAndAverage(float p) {
  g_pressBuf[g_pressBufIdx++] = p;
  if (g_pressBufIdx >= AVG_WINDOW) { g_pressBufIdx = 0; g_pressBufFilled = true; }
  uint8_t n = g_pressBufFilled ? AVG_WINDOW : g_pressBufIdx;
  float s = 0;
  for (uint8_t i = 0; i < n; i++) s += g_pressBuf[i];
  return s / n;
}

void resetPressureFilter() {
  g_pressBufIdx = 0;
  g_pressBufFilled = false;
}

// ================== ZHL-16C Buhlmann (air, N2 only) ==================
// 16 theoretical tissue compartments. Schreiner equation, instant constant depth.
// a/b parameters from ZHL-16C, atm units (1 bar = 0.987 atm; we work in bar).
static const float HALF_TIMES_N2[16] = {
   4.0f,   8.0f,  12.5f,  18.5f,  27.0f,  38.3f,  54.3f,  77.0f,
 109.0f, 146.0f, 187.0f, 239.0f, 305.0f, 390.0f, 498.0f, 635.0f
};
static const float A_N2[16] = {
  1.2599f, 1.0000f, 0.8618f, 0.7562f, 0.6667f, 0.5933f, 0.5282f, 0.4701f,
  0.4187f, 0.3798f, 0.3497f, 0.3223f, 0.2971f, 0.2737f, 0.2523f, 0.2327f
};
static const float B_N2[16] = {
  0.5050f, 0.6514f, 0.7222f, 0.7825f, 0.8126f, 0.8434f, 0.8693f, 0.8910f,
  0.9092f, 0.9222f, 0.9319f, 0.9403f, 0.9477f, 0.9544f, 0.9602f, 0.9653f
};

// Inert gas tension in each compartment, units = bar (N2 partial pressure)
float g_pN2[16];

// Air = 79% N2, surface ambient = 1.013 bar -> initial = 0.79 * 1.013
void initCompartmentsToSurface() {
  float pAlv0 = 0.79f * (g_surfacePressure / 1000.0f);
  for (int i = 0; i < 16; i++) g_pN2[i] = pAlv0;
}

// Update each compartment using Schreiner equation, dt in seconds, depth in m
void updateCompartments(float dt_sec, float depth_m) {
  float pAmb_bar = (g_surfacePressure / 1000.0f) + depth_m * g_fluidDensity * 9.80665f / 1e5f;
  float pAlv     = 0.79f * pAmb_bar;
  for (int i = 0; i < 16; i++) {
    float k = 0.6931472f / (HALF_TIMES_N2[i] * 60.0f);   // ln(2)/T1/2 (per second)
    g_pN2[i] += (pAlv - g_pN2[i]) * (1.0f - expf(-k * dt_sec));
  }
}

// NDL in minutes: time at current depth until any compartment reaches its M-value.
// Returns 99.0 (cap) if no compartment is loading or already saturated.
// 应用保守度因子: M-value 乘以 (g_conservatism / 100.0).
//   100% = 标准 ZHL-16C
//   80%  = 更激进 (NDL 增加)
//   120% = 更保守 (NDL 减少, 推荐 DIY)
float computeNDL(float depth_m) {
  float pAmb_bar = (g_surfacePressure / 1000.0f) + depth_m * g_fluidDensity * 9.80665f / 1e5f;
  float pAlv     = 0.79f * pAmb_bar;
  float consFactor = (float)g_conservatism / 100.0f;
  // 反向: 保守度大于 100 → M-value 阈值要小 → 提早达到 → NDL 短
  // M_effective = M / consFactor   (consFactor 大于 1 → M 小)
  float ndl_min  = 99.0f;
  for (int i = 0; i < 16; i++) {
    float Mv = (pAmb_bar / B_N2[i] + A_N2[i]) / consFactor;
    if (g_pN2[i] >= Mv) return 0.0f;
    if (pAlv <= g_pN2[i]) continue;
    float ratio = 1.0f - (Mv - g_pN2[i]) / (pAlv - g_pN2[i]);
    if (ratio <= 0.0f) continue;
    float k = 0.6931472f / (HALF_TIMES_N2[i] * 60.0f);
    float t_sec = -logf(ratio) / k;
    float t_min = t_sec / 60.0f;
    if (t_min < ndl_min) ndl_min = t_min;
  }
  return ndl_min;
}

// 估算海拔 (m), 基于水面气压 (mbar)
// 国际标准大气模型: alt = 44330 * (1 - (P/P0)^(1/5.255))
float estimateAltitudeM() {
  float ratio = g_surfacePressure / 1013.25f;
  return 44330.0f * (1.0f - powf(ratio, 1.0f / 5.255f));
}

// Highest tissue load percent vs M-value at current depth (0..100+)
float computeTissueLoadPct(float depth_m) {
  float pAmb_bar = (g_surfacePressure / 1000.0f) + depth_m * g_fluidDensity * 9.80665f / 1e5f;
  float consFactor = (float)g_conservatism / 100.0f;
  float maxPct = 0;
  for (int i = 0; i < 16; i++) {
    float Mv = (pAmb_bar / B_N2[i] + A_N2[i]) / consFactor;
    float pct = (g_pN2[i] / Mv) * 100.0f;
    if (pct > maxPct) maxPct = pct;
  }
  return maxPct;
}

// Ceiling (最浅可上升深度, m). 0 = 可直接上水面
float computeCeiling() {
  float consFactor = (float)g_conservatism / 100.0f;
  float maxCeilBar = g_surfacePressure / 1000.0f;
  for (int i = 0; i < 16; i++) {
    // Bühlmann: pAmb_min = (pN2 - A*consFactor) * B (反求允许的最小环境压)
    float pAmb_min = (g_pN2[i] - A_N2[i] / consFactor) * B_N2[i] * consFactor;
    if (pAmb_min > maxCeilBar) maxCeilBar = pAmb_min;
  }
  // bar -> m
  float ceil_m = (maxCeilBar - g_surfacePressure / 1000.0f) * 1e5f / (g_fluidDensity * 9.80665f);
  return ceil_m > 0 ? ceil_m : 0;
}
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
void loop() {
  uint32_t now = millis();

  // ---- Buttons ----
  btnPoll(g_btnMode, now);
  btnPoll(g_btnUp,   now);
  btnPoll(g_btnDown, now);

  // ---- 长按 MODE 5 秒 -> 关机 (深度睡眠) ----
  // 编辑/设置模式下不触发, 避免覆盖"长按保存"
  static bool s_shutdownArmed = false;
  if (!g_btnMode.stable && (now - g_btnMode.pressedAtMs) > 5000 && !s_shutdownArmed
      && !g_editingTime && !g_inSettings) {
    s_shutdownArmed = true;
    enterDeepSleep();
    // 不会返回
  }
  if (g_btnMode.stable) s_shutdownArmed = false;  // 松手重置

  // ---- OTA 触发: 3 种方式 ----
  //  1) 长按 UP 5 秒  2) 长按 DOWN 5 秒  3) 串口发 "OTA\n"
  static uint32_t s_otaUpStart = 0;
  static uint32_t s_otaDnStart = 0;
  static uint32_t s_otaLogMs = 0;

  bool upHeld   = !g_btnUp.stable;
  bool downHeld = !g_btnDown.stable;

  if (upHeld) {
    if (s_otaUpStart == 0) {
      s_otaUpStart = now;
      Serial.println("[OTA] UP pressed");
    }
  } else {
    if (s_otaUpStart != 0) Serial.println("[OTA] UP released");
    s_otaUpStart = 0;
  }
  if (downHeld) {
    if (s_otaDnStart == 0) {
      s_otaDnStart = now;
      Serial.println("[OTA] DOWN pressed");
    }
  } else {
    if (s_otaDnStart != 0) Serial.println("[OTA] DOWN released");
    s_otaDnStart = 0;
  }

  if (now - s_otaLogMs > 1000) {
    s_otaLogMs = now;
    if (s_otaUpStart > 0)
      Serial.printf("[OTA] UP held %lums\n", (unsigned long)(now - s_otaUpStart));
    if (s_otaDnStart > 0)
      Serial.printf("[OTA] DOWN held %lums\n", (unsigned long)(now - s_otaDnStart));
  }

  bool triggerOTA = false;
  if (s_otaUpStart > 0 && now - s_otaUpStart > 5000) triggerOTA = true;
  if (s_otaDnStart > 0 && now - s_otaDnStart > 5000) triggerOTA = true;

  // 串口命令触发: 发 "OTA\n" 即可 (最可靠, 绕过按键)
  while (Serial.available()) {
    static String cmdBuf = "";
    char c = Serial.read();
    if (c == '\n' || c == '\r') {
      if (cmdBuf.equalsIgnoreCase("OTA")) {
        Serial.println("[OTA] serial cmd OTA → trigger");
        triggerOTA = true;
      }
      cmdBuf = "";
    } else if (cmdBuf.length() < 16) {
      cmdBuf += c;
    }
  }

  if (triggerOTA && !g_editingTime && !g_inSettings) {
    Serial.println("[ACTION] → schedule BLE OTA boot");
    beepBlocking(3, 100);
    otaScheduleNextBoot();
  }

  // ---- OTA 标记 valid (启动 5s 后, 防止误回滚) ----
  otaMarkValidIfReady();

  // ---- Power saving: wake / sleep OLED ----
  bool anyBtnEvent = g_btnMode.evShort || g_btnMode.evLong ||
                     g_btnUp.evShort   || g_btnUp.evLong   ||
                     g_btnDown.evShort || g_btnDown.evLong;
  if (anyBtnEvent || g_diving) {
    g_lastInteractMs = now;
    if (g_screenOff) {
      g_screenOff = false;
      digitalWrite(TFT_BL_PIN, TFT_BL_ON);  // 开背光
      setCpuFrequencyMhz(CPU_FREQ_ACTIVE);  // 唤醒回 240MHz
      // 屏保期间屏幕残留旧帧, 强制全屏重画当前页
      tft.fillScreen(C(RGB_ORANGE));
      s_lastPage = 255;
      g_pageDirty = true;
      Serial.println("[POWER] CPU 240MHz / BL on");
      // Consume the wake-up button event (don't trigger an action)
      if (anyBtnEvent) {
        g_btnMode.evShort = g_btnMode.evLong = false;
        g_btnUp.evShort   = g_btnUp.evLong   = false;
        g_btnDown.evShort = g_btnDown.evLong = false;
      }
    }
  }
  if (!g_screenOff && !g_editingTime && !g_diving &&
      (now - g_lastInteractMs > g_screenOffMs)) {
    g_screenOff = true;
    tft.fillScreen(C(RGB_BLACK));          // 先黑屏, 避免残影 + 让屏保 saver 干净起步
    digitalWrite(TFT_BL_PIN, TFT_BL_OFF);  // 关背光 (~40mA)
    setCpuFrequencyMhz(CPU_FREQ_IDLE);     // 降 80MHz 省电 ~30%
    Serial.println("[POWER] CPU 80MHz / BL off");
    g_saverNeedsRedraw = true;             // 强制 saver 下次渲染 fillScreen + 重画
  }

  // ---- Battery (every 5s) ----
  updateBattery(now);

  if (g_editingTime) {
    // ---- Time-edit mode: buttons remapped ----
    if (g_btnMode.evShort) {
      g_btnMode.evShort = false;
      g_editField = 1 - g_editField;
      g_pageDirty = true;                          // 触发重画
    }
    if (g_btnMode.evLong) {
      g_btnMode.evLong = false;
      // Save and exit
      setSystemClock(g_editHH, g_editMM, 0);
      saveClockToNVS();
      g_editingTime = false;
      g_pageDirty = true;
      Serial.printf("[ACTION] Clock set to %02u:%02u\n", g_editHH, g_editMM);
      beepBlocking(2, 80);
    }
    if (g_btnUp.evShort) {
      g_btnUp.evShort = false;
      if (g_editField == 0) g_editHH = (g_editHH + 1) % 24;
      else                  g_editMM = (g_editMM + 1) % 60;
      g_pageDirty = true;
    }
    if (g_btnDown.evShort) {
      g_btnDown.evShort = false;
      if (g_editField == 0) g_editHH = (g_editHH + 23) % 24;
      else                  g_editMM = (g_editMM + 59) % 60;
      g_pageDirty = true;
    }
    g_btnUp.evLong = false;
    g_btnDown.evLong = false;
  } else if (g_inSettings) {
    // ---- Settings menu: buttons remapped ----
    if (g_btnMode.evShort) {
      g_btnMode.evShort = false;
      g_settingsItem = (g_settingsItem + 1) % SETTINGS_COUNT;
      g_pageDirty = true;                          // 触发重画
    }
    if (g_btnMode.evLong) {
      g_btnMode.evLong = false;
      saveSettingsToNVS();
      g_inSettings = false;
      g_pageDirty = true;
      beepBlocking(2, 80);
      Serial.println("[ACTION] Settings saved & exit");
    }
    if (g_btnUp.evShort) {
      g_btnUp.evShort = false;
      settingsItemAdjust(g_settingsItem, +1);
      g_pageDirty = true;                          // 改值后强制重画显示新值
    }
    if (g_btnDown.evShort) {
      g_btnDown.evShort = false;
      settingsItemAdjust(g_settingsItem, -1);
      g_pageDirty = true;
    }
    g_btnUp.evLong = false;
    g_btnDown.evLong = false;
  } else {
    // ---- Normal mode ----
    if (g_btnMode.evShort) {
      g_btnMode.evShort = false;
      g_page = (g_page + 1) % PAGE_COUNT;
      if (g_page == PAGE_LOG) g_logViewIdx = 0;
    }
    if (g_btnMode.evLong) {
      g_btnMode.evLong = false;
      calibrateSurface();
    }
    if (g_btnUp.evShort) {
      g_btnUp.evShort = false;
      if (g_page == PAGE_LOG) {
        if (g_logCount > 0 && g_logViewIdx > 0) g_logViewIdx--;
      } else if (g_page == PAGE_PLAN) {
        // 计划深度 + 1 (限 1-50m)
        if (g_planDepthM < 50) g_planDepthM++;
      } else {
        g_maxDepth = 0;
        Serial.println("[ACTION] Max depth reset");
        beepBlocking(1, 60);
      }
    }
    if (g_btnUp.evLong) {
      g_btnUp.evLong = false;
      // 长按 UP -> 进入设置菜单 (原"切水"功能挪进菜单)
      g_inSettings = true;
      g_settingsItem = 0;
      Serial.println("[ACTION] Enter settings");
      beepBlocking(1, 100);
    }
    if (g_btnDown.evShort) {
      g_btnDown.evShort = false;
      if (g_page == PAGE_LOG) {
        if (g_logCount > 0 && g_logViewIdx < g_logCount - 1) g_logViewIdx++;
      } else if (g_page == PAGE_PLAN) {
        // 计划深度 - 1 (限 1-50m)
        if (g_planDepthM > 1) g_planDepthM--;
      } else if (g_diving) {
        g_diveStartMs = now;
        Serial.println("[ACTION] Dive timer reset");
        beepBlocking(1, 60);
      }
    }
    if (g_btnDown.evLong) {
      g_btnDown.evLong = false;
      if (g_page == PAGE_LOG) {
        eraseLogNVS();
        Serial.println("[ACTION] Log erased");
        beepBlocking(3, 70);
      } else {
        // Enter time-edit mode, prefill with current clock
        uint8_t hh, mm, ss;
        getCurrentTime(hh, mm, ss);
        g_editHH = hh;
        g_editMM = mm;
        g_editField = 0;
        g_editingTime = true;
        Serial.println("[ACTION] Enter clock edit");
        beepBlocking(1, 100);
      }
    }
  }

  // ---- Sample ----
  if (now - g_lastSampleMs < SAMPLE_MS) return;
  uint32_t dtMs = now - g_lastSampleMs;
  g_lastSampleMs = now;

  if (g_sensorOk) {
    sensor.read();
    float pRead = sensor.pressure();
    float tRead = sensor.temperature();
    // 合理性检查 (大气 ~1013 mbar, 60m 水深 ~7000 mbar; 温度 -10..50°C)
    // 单次坏数据丢弃避免毒化 EMA 滤波
    if (pRead < 200.0f || pRead > 8000.0f || isnanf(pRead)) {
      // 不更新, 保持上次值 (传感器临时抖动 / I2C 错误)
    } else {
      g_pressureRaw = pRead;
      if (!isnanf(tRead) && tRead > -10.0f && tRead < 60.0f) g_temp = tRead;
      float pSmooth = pushPressureAndAverage(g_pressureRaw);
      g_depthRaw    = depthFromPressure(g_pressureRaw);
      g_depthSmooth = depthFromPressure(pSmooth);
      // 防 dtMs=0 触发除零 Inf (极端竞态)
      if (dtMs > 0) g_ascentMpm = (g_lastDepth - g_depthSmooth) * 60000.0f / (float)dtMs;
      g_lastDepth   = g_depthSmooth;
      if (g_depthSmooth > g_maxDepth) g_maxDepth = g_depthSmooth;
      if (g_temp < g_diveMinTemp) g_diveMinTemp = g_temp;
    }

    // Update tissues every sample
    updateCompartments(dtMs / 1000.0f, g_depthSmooth);

    // Record temperature sample (rate-limited to 1/min internally)
    recordTempSample(now);
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

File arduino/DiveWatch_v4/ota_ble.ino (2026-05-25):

// =====================================================================
// 刷不死方案 v3: NimBLE 配 WiFi + WiFi OTA (节省 ~150KB Flash)
// =====================================================================
#include <NimBLEDevice.h>
#include <WiFi.h>
#include <ArduinoOTA.h>
#include <WebServer.h>
#include <Update.h>
#include <esp_ota_ops.h>

WebServer g_otaWeb(80);

#define OTA_SVC_UUID  "1d14d6ee-fd63-4fa1-bfa4-8f47b42119f0"
#define OTA_SSID_UUID "f7bf3564-fb6d-4e53-88a4-5e37e0326063"
#define OTA_PSK_UUID  "984227f3-34fc-4045-a5d0-2c581f81a153"
#define OTA_CMD_UUID  "0c533cef-d6b0-4ba2-9f08-7d6cea1b3e7e"
#define OTA_STAT_UUID "3b1f9c5e-8a72-4d11-9b3a-7c4e2f1a5d80"

bool     g_otaMode      = false;
bool     g_otaWifiOk    = false;
bool     g_otaRunning   = false;
String   g_otaSsid      = "";
String   g_otaPsk       = "";
String   g_otaIp        = "";
int      g_otaProgress  = 0;
NimBLECharacteristic *g_otaStatCh = nullptr;

// 由主 sketch 提供
void otaDrawScreen(const char *line1, const char *line2, int pct);

static void otaNotify(const char *msg) {
  Serial.printf("[OTA] %s\n", msg);
  if (g_otaStatCh) {
    g_otaStatCh->setValue((uint8_t*)msg, strlen(msg));
    g_otaStatCh->notify();
  }
}

// ---------------- WiFi 凭据持久化 ----------------
static void otaSaveWifiCreds(const String &ssid, const String &psk) {
  Preferences p;
  if (p.begin("ota", false)) {
    p.putString("ssid", ssid);
    p.putString("psk", psk);
    p.end();
  }
}
static bool otaLoadWifiCreds(String &ssid, String &psk) {
  Preferences p;
  if (!p.begin("ota", true)) return false;
  ssid = p.getString("ssid", "");
  psk  = p.getString("psk", "");
  p.end();
  return ssid.length() > 0;
}
static void otaForgetWifiCreds() {
  Preferences p;
  if (p.begin("ota", false)) {
    p.remove("ssid"); p.remove("psk");
    p.end();
  }
}

// ---------------- WiFi + ArduinoOTA ----------------
static void otaStartWifiOTA() {
  otaNotify("WIFI_CONNECTING");
  otaDrawScreen("连接 WiFi", g_otaSsid.c_str(), 0);
  WiFi.mode(WIFI_STA);
  WiFi.begin(g_otaSsid.c_str(), g_otaPsk.c_str());
  uint32_t t0 = millis();
  while (WiFi.status() != WL_CONNECTED && millis() - t0 < 20000) {
    delay(200);
  }
  if (WiFi.status() != WL_CONNECTED) {
    otaNotify("WIFI_FAIL");
    otaDrawScreen("WiFi 连接失败", "请重试", -1);
    g_otaWifiOk = false;
    return;
  }
  g_otaWifiOk = true;
  g_otaIp = WiFi.localIP().toString();
  String msg = "WIFI_OK " + g_otaIp;
  otaNotify(msg.c_str());

  otaSaveWifiCreds(g_otaSsid, g_otaPsk);

  ArduinoOTA.setHostname("DiveWatch");
  ArduinoOTA.setPort(3232);
  ArduinoOTA.onStart([]() {
    g_otaRunning = true;
    g_otaProgress = 0;
    otaNotify("OTA_BEGIN");
    otaDrawScreen("接收固件", "", 0);
  });
  ArduinoOTA.onProgress([](unsigned int p, unsigned int total) {
    int pct = (total > 0) ? (int)(p * 100 / total) : 0;
    if (pct != g_otaProgress) {
      g_otaProgress = pct;
      char buf[32]; snprintf(buf, sizeof(buf), "OTA_PROGRESS %d", pct);
      otaNotify(buf);
      char ln[32]; snprintf(ln, sizeof(ln), "%u / %u KB", p/1024, total/1024);
      otaDrawScreen("接收固件", ln, pct);
    }
  });
  ArduinoOTA.onEnd([]() {
    otaNotify("OTA_END");
    otaDrawScreen("刷写完成", "重启中...", 100);
    delay(500);
  });
  ArduinoOTA.onError([](ota_error_t e) {
    const char *desc = "未知";
    switch (e) {
      case OTA_AUTH_ERROR:    desc = "认证失败"; break;
      case OTA_BEGIN_ERROR:   desc = "BEGIN失败"; break;
      case OTA_CONNECT_ERROR: desc = "连接失败"; break;
      case OTA_RECEIVE_ERROR: desc = "接收丢包"; break;
      case OTA_END_ERROR:     desc = "END校验失败"; break;
    }
    char buf[60]; snprintf(buf, sizeof(buf), "ERR %d %s", (int)e, desc);
    otaNotify(buf);
    otaDrawScreen("OTA 错误", buf, -1);
    Serial.printf("[OTA] error %d (%s), state can retry\n", (int)e, desc);
    // 不重启, 让 ArduinoOTA 内部可以接受下一次 invitation 重试
  });
  ArduinoOTA.begin();

  // ---- HTTP Web 服务 (端口 80) ----
  g_otaWeb.on("/", HTTP_GET, []() {
    String html = F("<!DOCTYPE html><html><head><meta charset='UTF-8'>"
                    "<title>DiveWatch OTA</title>"
                    "<style>body{font-family:-apple-system,sans-serif;max-width:480px;"
                    "margin:30px auto;padding:0 20px}h1{color:#FF6600}"
                    ".card{background:#f5f5f5;border-radius:8px;padding:16px;margin:12px 0}"
                    "button,input[type=submit]{background:#FF6600;color:#fff;border:0;"
                    "padding:12px 24px;border-radius:6px;font-size:15px;cursor:pointer;width:100%}"
                    "input[type=file]{width:100%;padding:10px;margin:8px 0}"
                    ".bar{background:#eee;border-radius:6px;height:24px;overflow:hidden;margin:12px 0}"
                    ".fill{background:#FF6600;height:100%;width:0;transition:width 0.2s}"
                    "</style></head><body>"
                    "<h1>🔄 DiveWatch OTA</h1>"
                    "<div class='card'>"
                    "<p>设备在线 ✓ &nbsp;|&nbsp; 内存 ");
    html += String(ESP.getFreeHeap()/1024) + "/" + String(ESP.getHeapSize()/1024) + " KB</p>"
            "<p>IP: " + g_otaIp + " &nbsp;|&nbsp; Sketch: " +
            String(ESP.getSketchSize()/1024) + " KB</p>"
            "<p>当前 slot: " + esp_ota_get_running_partition()->label +
            " &nbsp;|&nbsp; 下次写入: " + (esp_ota_get_next_update_partition(NULL) ?
              esp_ota_get_next_update_partition(NULL)->label : "?") + "</p>"
            "</div><div class='card'>"
            "<h3>上传固件</h3>"
            "<form id='f' method='POST' action='/update' enctype='multipart/form-data'>"
            "<input type='file' name='firmware' accept='.bin' required>"
            "<input type='submit' value='📤 开始刷写'>"
            "</form>"
            "<div class='bar'><div class='fill' id='b'></div></div>"
            "<div id='st'></div>"
            "</div><div class='card'>"
            "<button onclick=\"fetch('/restart').then(_=>alert('已重启'))\">↻ 重启设备</button>"
            "</div>"
            "<script>"
            "document.getElementById('f').onsubmit=function(e){e.preventDefault();"
            "var fd=new FormData(this);var x=new XMLHttpRequest();"
            "x.upload.onprogress=function(ev){if(ev.lengthComputable){"
            "var p=Math.round(ev.loaded*100/ev.total);"
            "document.getElementById('b').style.width=p+'%';"
            "document.getElementById('st').innerText='上传 '+p+'%'}};"
            "x.onload=function(){document.getElementById('st').innerText="
            "x.status==200?'✓ 完成! 设备重启中':'✗ 失败: '+x.responseText};"
            "x.open('POST','/update');x.send(fd);};"
            "</script></body></html>";
    g_otaWeb.send(200, "text/html; charset=utf-8", html);
  });

  g_otaWeb.on("/restart", HTTP_GET, []() {
    g_otaWeb.send(200, "text/plain", "restarting");
    delay(300); ESP.restart();
  });
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

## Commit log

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2026-05-15 DiveWatch v2: ZHL-16C NDL, 3 buttons, multi-page UI, NVS log, battery
    - Switch to Arduino Nano ESP32 pin labels (A4/A5 I2C, D2 buzzer, D3/D4/D7 buttons)
    - ZHL-16C 16-compartment Buhlmann tissue tracker, NDL computation
    - Safety stop detection at 5m +/- 1.5m with 3 min countdown
    - Moving-average smoothing on pressure
    - Debounced 3-button input with short/long press events
    - 4 pages: HUD, Tissue load bar graph, Last dive, Log list
    - Persistent dive log (last 10) via Preferences/NVS
    - Battery voltage via A0 ADC with 100k+100k divider, % via Li-ion piecewise curve
    - Alarms: depth >30m, ascent >9m/min, NDL=0, safety stop done
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2026-05-15 v2.3: 设置菜单 + 字体升级 chinese3 + 符号替换
    设置菜单 (长按 UP 进入, 长按 MODE 保存退出):
    - 深度报警 5-60m (步长 5)
    - 上升警告 3-18 m/min (步长 1)
    - 屏保超时 1-30 min (步长 1)
    - 安全停留 60-300 s (步长 30)
    - 蜂鸣器开关 (开/关)
    - 水密度 (海水/淡水)
    - 全部 NVS 持久化, 重启保留
    - 长按 UP 原'切水'功能挪进菜单
    - 蜂鸣器关闭时所有 beepBlocking 静默
    字体兼容性修复:
    - 字体 wqy12_t_chinese1 -> chinese3 (覆盖 GB2312 全集 ~7000 字)
    - ℃ 替换为 度 (避免 chinese1 集外字符)
    - kg/m³ 替换为 kg/m3 (上标 3 同样问题)
    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
2026-05-15 v2.6: 修复安全停留触发 + HUD 电池/计时重叠
    修复 1: 安全停留触发阈值 10m -> 5m
    - updateSafetyStop 中 g_ssArmCondition 触发深度从 10m 降到 5m
    - 更符合 PADI '建议每潜安全停留' 标准
    - 测试时手指挤压 MS5837 也能轻松触发
    修复 2: HUD 顶部潜水时长与电池图标 X 坐标重叠 (72-85)
    - 潜水时: 不画电池图标, 显示纯数字 87% (避免重叠)
    潜水时长格式 '潜 0:23' 紧贴时钟右边 x=36
    - 水面时: 仍画电池图标 + 百分比 (中央留空)
    - 海/淡水标识固定 x=118 永远在最右
    潜水时长记录逻辑 (无需改动):
    - 开始 g_depthSmooth > 1.2m, 结束 g_depthSmooth < 0.5m (hysteresis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
2026-05-16 v2.7: 字体彻底修复 chinese3 -> gb2312 全集
    问题: wqy12_t_chinese3 子集实际只覆盖约 3000 字, 仍缺
    常用字 '器' '海' '置' 等 -> 用户报 '设置只显示一个设'
    修复: 换 wqy12_t_gb2312 包含完整 GB2312 6700 字集
    - 固件 28% -> 34% (多 190KB), 仍剩 66% 余量
    - 所有 GB2312 字符均可显示, 不会再丢字
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2026-05-16 v2.9: 6 项一揽子 + 气量改为 bar 计算
    气量按 bar 计算 (符合气压表 SPG 习惯):
    - g_initialAirL 拆为 g_initialBar(bar) + g_tankVolL(L)
    - 总气量 = bar * L (helper: totalAirL())
    - 显示用 bar/min, 剩压 X bar, 报警 < 50 bar
    - DiveRecord airUsedL 仍按 L 存储, 显示转 bar
    新功能 (6 项):
    1. NDL 计划器 (新页 PAGE_PLAN, 第 3 页)
    - UP/DOWN 短按改计划深度 (1-50m)
    - 显示该深度 NDL + 满瓶 Air Time
    2. 保守度因子 (设置 80-120%, 默认 100%)
    - computeNDL 中 M-value 除以保守度因子
    - 120% = M 减小 -> NDL 缩短 -> 更安全
    3. 海拔修正显示 (STATS 页右上)
    - estimateAltitudeM() 标准大气模型
    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
2026-05-16 电池校准: BAT_DIVIDER 可调 + analogReadMilliVolts + OCV 表
    修复 #1: 用 analogReadMilliVolts() 替代 analogRead()*3.3/4095
    - 内置 eFuse 校准曲线, ADC 读数更准
    修复 #2: BAT_DIVIDER 从 2.0 调到 2.10 (4.7k ±5% 电阻误差校正)
    - 实测: ADC 2002mV * 2.10 = 4.204V (满电正确)
    - 之前 BAT_DIVIDER=2.0 时显示 4.00V 偏低 0.20V
    修复 #3: BAT_DIVIDER 加入设置菜单 (第 12 项, 1.80-2.30 步 0.02)
    - 不同电阻批次可微调, NVS 持久化, 无需改代码重烧
    - 进入设置 -> 翻到 '电池校准' -> 上下键调整 -> 长按 MODE 保存
    修复 #4: OCV 表精修 (Battery University 18650 典型曲线)
    - 之前 4.10V=87% 偏低
    - 现在 4.10V=95% 4.05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
2026-05-16 v3.2: 修复 '安全停' 文字截断 + Light Sleep 屏保省电
    修复文字截断:
    - HUD 中部行 '安全停%lu秒' -> '安全停留 %lu 秒' (完整 4 字)
    - 'NDL %2.0f分' -> 'NDL %2.0f 分' (加空格美化)
    - 'NDL>99分' -> 'NDL >99 分' (统一空格)
    - '需减压!' -> '需要减压!' (完整)
    - 安全停留/减压/SS完成 状态时不再显示右侧 '最深' (避免挤位)
    Light Sleep 屏保省电:
    - 屏保激活且非潜水/编辑/设置时, 调用 esp_light_sleep_start()
    - 唤醒源: ext1 任一按键 GPIO LOW + 5秒 timer
    - 唤醒后 loop 自然继续
    - 按键醒 -> 下次顶部 anyBtnEvent 触发恢复屏幕
    - Timer 醒 -> 周期性更新电池/MS5837, 再次睡
    功耗对比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
2026-05-16 v3.3: 全 UI 对齐审查与修复 (无溢出无截断)
    经过逐项 width 估算审查 (Python 脚本批量检查), 发现并修复 3 处微溢出:
    1. drawHud 警告标志 '!' '^' 从 x=123 -> x=120
    (ASCII 6px, x=123 时右边缘 129 微超 1px)
    2. drawTimeEdit 'MODE确定' 从 x=82 -> x=80
    (4 ASCII + 2 中文 = 48px, x=82 时右边缘 130 超 2px)
    3. drawSplash 'v2.3' -> 'v3.2' 版本号更新
    审查结果 (所有页面):
    - HUD 5 行布局对齐 OK (顶/大字/中部/底部)
    - 组织负荷柱状图 + NDL 标签 OK
    - NDL 计划器 (4 行最大宽 108px ≤ 128) OK
    - 气量监控 (4 行最大宽 120px) OK
    - 温度/电池趋势图 Y 轴标签对齐 OK
    - 上次潜水/日志列表 (实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
2026-05-16 v3.4: 修复开机自检'按键异常'误报
    根因:
    - 长按 MODE 2 秒+ 唤醒开机时, 自检运行时 MODE 仍被按住
    - 自检读 digitalRead == HIGH 判 OK, LOW 判异常
    - MODE 按住 -> LOW -> 误报 '按键异常'
    修复:
    - 自检前先检测是否有按键被按住 (anyHeld)
    - 如果有, 在屏幕加 '请松开按键' 提示
    - 等待最多 3.5 秒, 所有按键释放后再判电平
    - 全部释放后稳定 50ms (防抖) 再读
    - 解决长按开机 + 误触场景
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2026-05-16 v3.6: 体内氮气安全页 (PAGE_N2) - 4 个公开算法
    基于现有 ZHL-16C 16 房间 Bühlmann 模型, 新增 4 个衍生安全指标:
    1. 氮气负荷 % (computeTissueLoadPct)
    - 最大组织室 P_N2 / 该室 M-value × 100%
    - 现在应用保守度因子 (M_eff = M / consFactor)
    - 修复了之前未应用保守度的 bug
    2. 单室饱和度 % (computeSaturationPct)
    - 当前 P_N2 相对于该深度平衡值的百分比
    - 0% = 水面平衡, 100% = 在此深度饱和
    - 显示最快 (4min) 和最慢 (635min) 组织室
    3. NoFly Time 禁飞时间 (computeNoFlyTimeHours)
    - 飞机舱压 600mbar (标准巡航 ~2400m 海拔)
    - 每个组织室回到 < 飞行 M-value 所需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
2026-05-16 v3.7: 修复右边遮盖 + 按键自检诊断 + 开机回 HUD
    修复 1: 屏幕右侧文字被物理边框遮盖
    - 1.3 寸 SH1106 模块右边缘 1-2 像素常被封装裁剪
    - 所有右对齐 drawUTF8 从 (128 - w) 改为 (126 - w)
    - 留 2 px 安全边距, 16 处全部统一修改
    修复 2: 按键自检误报 + 诊断信息
    - 之前: 一次性 digitalRead, 抖动/未释放都报异常
    - 现在: checkBtnStable lambda, 等待 '连续 500ms 稳定 HIGH'
    - MODE 给 4 秒(可能是开机长按), UP/DOWN 各 1 秒
    - 自检结果分别显示: '键 M:OK U:OK D:X' 直接看出哪个按键有问题
    - 串口输出 BTN_M/BTN_U/BTN_D 三个独立状态
    修复 3: 开机自动进入设置时间页 (bug)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
2026-05-16 v3.9: UI 边距全面收紧 (4px 安全边距)
    发现 1 处真溢出 + 几处近边, 全部修复:
    1. drawN2 文字溢出 (worst 132px):
    '快99% 慢99% (16室)' -> '快 99% 慢 99%'
    标题 '体内氮气' -> '体内氮气 ZHL-16' (把模型信息挪标题)
    2. drawSettings 滚动指示 ^v: x=122 -> 118 (留 4px)
    3. drawTimeEdit:
    'MODE确定' (48px) -> 'MODE OK' (42px), x=82 留 4px
    4. drawHud 警告标志 !^v: x=120 -> 118 (留 4px)
    修复后所有 UI 文本右边界 ≤ 124px (留 ≥ 4px 安全边距),
    即使 OLED 物理边框裁剪 2-3px 也不会丢字符.
2026-05-18 设计紧凑型防水外壳 60×65×22mm (OpenSCAD 参数化模型)
    case/divewatch_case.scad:
    - 上盖 12mm + 下底 10mm 两半结构
    - 圆角矩形 60×65mm, 圆角 R4
    - 表带耳 22mm (兼容通用表带)
    - OLED 显示窗口 27×17mm (顶部)
    - 3 按钮通孔 ⌀6.5mm 左侧 (MODE/UP/DOWN, 12mm 间距)
    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
    [divewatch_case.scad]
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2026-05-19 修复 ST7789 黑屏: 显式配置 SPI bus 引脚
    - Adafruit_ST7789(cs, dc, rst) 用 Arduino 默认 SPI 实例
    - ESP32-S3 默认 SPI 引脚: MOSI=11, MISO=13, SCK=12
    - 但用户接的是 D11=GPIO38, D13=GPIO48 (Nano 板的 SPI 默认)
    - 默认 SPI 还跟 I2C (GPIO 11/12) 冲突 -> 雪花/黑屏
    - SPIClass mySPI(HSPI) 显式创建 HSPI 总线
    - Adafruit_ST7789(&mySPI, cs, dc, rst) 用自定义 bus
    - mySPI.begin(SCK=48, MISO=-1, MOSI=38, SS) 配引脚
    验证: SCK=48 MOSI=38 输出正常, 屏显示绿字 + 7 彩虹条
    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
2026-05-19 v4 HUD MVP: ST7789 横屏 320x240 橘黄背景 + 中文显示
    颜色模式定位:
    - 通过 4 种组合测试 (invert × swap RB) 锁定 TEST 4 为正确显示
    - 这块 ST7789 需要: invertDisplay(true) + R/B 字节互换
    - C() 宏统一包装颜色: tft.fillScreen(C(RGB_ORANGE))
    显示链路:
    - Adafruit_ST7789 + 自定义 HSPI bus (SCK=48 MOSI=38)
    - U8g2_for_Adafruit_GFX 桥接, 用 wqy16_t_gb2312 中文字体
    - 大字 logisoso50 显示深度
    HUD 布局 (320×240 横屏):
    y=0-30: 暗灰顶栏 (时间/潜水中/电池/海淡)
    y=40-130: 橘黄区, 深度大字 + 米 + 分隔线
    y=155-205: 数据行 (NDL/N2/最深/温度, 用颜色区分)
    y=210-240: 暗灰底栏 (操作提示)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
    [DiveWatch_v4.ino]
2026-05-19 v4 HUD MVP 完成: ST7789 横屏橘黄+中文显示
    锁定的颜色配置 (经多轮测试):
    - tft.invertDisplay(true) 必须开
    - C(x) = swapRB(x) wrap 所有颜色值
    - u8g2.setFontMode(0) solid 模式 (透明模式中文不显示)
    - u8g2.setBackgroundColor(C(RGB_ORANGE)) 必须与屏底色一致, 否则中文背景是黑色
    - 进入黑底栏前临时切 setBackgroundColor(C(RGB_BLACK))
    HUD 完整 4 段:
    y=0-32 顶栏 (黑底白字: 时钟 / 潜水时长绿 / 电池)
    y=40-130 大字深度 (橘黄底, logisoso50 50px 黑色)
    y=140 分隔线
    y=150-205 数据区 (NDL绿 / N2蓝 / 最深 / 温度)
    y=210-240 底栏 (黑底白字: 操作提示)
    下一步: 加按钮处理 + 接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
    [DiveWatch_v4.ino]
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2026-05-19 v4 修复三问题: 闪烁 / 菜单看不见 / 时间保存
    1. 编辑/设置模式下不触发 5 秒关机:
    - 长按 MODE 5s 关机检测加 !g_editingTime && !g_inSettings 守卫
    - 之前: 长按 MODE 想保存时间, 1.5s 触发 evLong 应保存,
    但继续按到 5s 仍触发关机, 数据可能没真保存就睡了
    2. drawSettings 闪烁修复:
    - static lastItem 缓存, 只在切项时重画
    - 没变化的情况下不重画 (避免 300ms 间隔重画 = 闪)
    3. drawTimeEdit 闪烁修复:
    - static lastH/lastM/lastF 缓存
    - 只在 HH/MM 或 字段切换时重画
    4. 强制 g_buzzerEnable=true + 开机蜂鸣测试 3 长鸣
    [DiveWatch_v4.ino]
2026-05-19 v4 修复设置按键不响应 + SPI 提速 40MHz 抗卡顿
    设置/编辑按键修复:
    - 之前 drawSettings 用 lastItem 缓存, 改值时 item 不变 -> 不重画 -> 看不到改动
    - 修复: 按 UP/DOWN/MODE 后都设 g_pageDirty=true 强制重画
    - 时间编辑按键同样处理
    SPI 提速:
    - setSPISpeed 10MHz -> 40MHz (4 倍)
    - 全屏传输 120ms -> 30ms
    - 显著缓解卡顿
    [DiveWatch_v4.ino]
2026-05-19 v4 HUD 重做为 Garmin Descent X50i 风格
    - 顶栏: 状态LED圆点 (绿/黄/红编码) + 时间 + DIVE/水面 + 用时 + AIR + 电量 + 海/淡
    - 主区: 大字深度居中 (logisoso50) + 12-dot NDL 圆环 (Φ156) + 圆心下方安停/减压
    - 上升速度横向彩条: 中央0左下负右上正, 6/9/12 mpm 黄/红阈值
    - 数据条: 最深 / N2% / 温度 / 用时 4列
    - 底栏: 黑底按键提示 MODE/UP/DOWN
    同时修复:
    - 安全停留显示不更新 (旧版被 NDL 缓存 gate, 现去掉)
    - 切换 huge_app 分区 + CDCOnBoot=cdc, 烧录后 USB CDC 保持在线
    [DiveWatch_v4.ino]
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2026-05-19 v4 HUD 大字重做 + 全局配色修正 (橘黄底对比)
    HUD 重构:
    - 去掉 NDL 圆环 (橘黄底上对比差, 浪费视觉空间)
    - 巨字深度 居中 (logisoso50, 50px 高) + 米单位同行
    - NDL 改为大字数字 (logisoso24) + "分" 标签 (左侧)
    - 安停徽章移到右侧 (与 NDL 同行)
    - 顶部加 "深度" 小标签
    - 4 列数据条: 最深 / 温度 / N2 / 用时
    配色修正 (橘黄底上):
    - 全局 setForegroundColor(RGB_DARK) -> BLACK
    (橘黄+深灰对比度 4.5, 橘黄+黑 7.5; 阴影变粗字效果)
    - NDL/SPG 圆环非活跃 dot: 深灰填充 -> 黑色空心圈
    (空心圈在橘黄底对比清晰, 内部仍是橘黄)
    - 屏保黑底唤醒提示: BLACK -> WHITE (修 s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
    [DiveWatch_v4.ino]
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2026-05-19 v4 死机扫描 + 3 个高风险修复
    1) drawSettings 滚动条 div by 0 (L2257):
    旧: thumbY = ... / (SETTINGS_COUNT - VISIBLE), 后才检查
    新: 先检查 SETTINGS_COUNT > VISIBLE 再除, 否则 thumbY = sbY
    2) checkBtnStable 49 天 millis() 回卷 (L2435):
    旧: while (millis() < deadline) 回卷后逻辑反转
    新: while ((uint32_t)(millis() - startMs) < timeoutMs) 无符号差分
    3) 采样 dtMs=0 触发 Inf (L2792):
    旧: g_ascentMpm = ... / (float)dtMs
    新: if (dtMs > 0) g_ascentMpm = ... 否则保持上次值
    经评审 安全的点 (不需要修):
    - g_tempHistCount / g_batHistCount 折线: 已有 count<2 提前 return
    - temp/bat 折线 max-min: 已有 < 0.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
    [DiveWatch_v4.ino]
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2026-05-19 v4 修正颜色 hex 映射 (RGB_RED 显示黄色问题)
    发现原因: invertDisplay(true) + swapRB 双重转换下颜色映射全部错位.
    之前 ORANGE/BLACK/WHITE 是巧合显示正确, 其他色全部错色.
    错位对照 (旧 hex / 实际显示):
    - RGB_RED 0xF800 -> 屏幕显示黄色
    - RGB_GREEN 0x07E0 -> 屏幕显示紫红
    - RGB_BLUE 0x001F -> 屏幕显示浅青
    - RGB_YELLOW 0xFFE0 -> 屏幕显示红色 (反过来了!)
    - RGB_CYAN 0x07FF -> 屏幕显示蓝色
    修正后 hex (按"屏幕显示意图"重新定义):
    - RGB_RED 0xFFE0 -> 屏幕显示红色 ✓
    - RGB_GREEN 0xF81F -> 屏幕显示绿色 ✓
    - RGB_BLUE 0x07FF -> 屏幕显示蓝色 ✓
    - RGB_YELLOW/CYAN 互换 (现在不用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
    [DiveWatch_v4.ino]
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2026-05-21 case: build123d 重写 + STEP + 3MF (ST7789 2.4 寸版)
    新外壳 (70 x 85 x 22 mm, 含表带耳 70 x 95):
    - top_cover.py / bottom_case.py: build123d Python 参数化源
    - top_cover.step / bottom_case.step: 主 CAD 格式 (可二次编辑)
    - top_cover.3mf / bottom_case.3mf: 拓竹 X2D / Bambu Studio 直接切片
    适配硬件升级:
    - ST7789 2.4 寸 SPI 屏 (替代 1.3 寸 OLED)
    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
    [bottom_case.3mf, bottom_case.step, top_cover.3mf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]
2026-05-21 case: 用 lib3mf 重新生成 3MF (Bambu Studio 兼容)
    问题: cad skill 默认导出的 3MF 使用 basematerials schema, 拓竹 Bambu Studio
    打开报"无几何数据"错误.
    - 新增 stl_to_3mf.py 转换器
    - 用 trimesh 读 STL, lib3mf (3MF Consortium 官方库) 写 3MF
    - 生成的 3MF 含 Production extension + UUID + 标准 mesh schema
    - 与 Bambu Studio / OrcaSlicer / 拓竹 X2D 等切片器兼容
    新工作流 (二次修改后):
    python3 ~/.claude/skills/cad/scripts/step top_cover.py --stl top_cover.stl
    python3 stl_to_3mf.py
    文件大小:
    - top_cover.stl 1.2 MB / .3mf 343 KB
    - bottom_case.stl 484 KB / .3mf 119 KB
    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
    [bottom_case.3mf, bottom_case.stl, top_cover.3mf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]
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2026-05-25 case_v5: 1.54寸屏自定义外壳 (53x81.5x44.4mm)
    硬件适配:
    - 屏幕显示区 44x60.6mm 显示窗 (顶盖)
    - 屏 PCB 45x73.5x1.2mm 沉槽 + 1.3mm FPC 排线避让凹槽
    - 3 按钮 ⌀3.3mm 在 -X 长侧面 (间距 13.1mm)
    - 压力传感器 3.6x3.6 方孔 深 3mm 在 +X 长侧面右上角
    - USB-C 9x3.3mm 在 -Y 端面中间高度
    - 电池仓 34x51x4.8mm + 4 角防晃凸点
    - 4 角 M2 螺丝 (沉头 + 自攻柱)
    - 上下盖间 O 圈密封槽 (周长 ~250mm, 2x1.2mm)
    注意:
    - 用户指定厚度 44.4mm (装下所有硬件后内腔有富余, 可塞泡棉)
    - 修复了螺丝柱直径 5mm 与内壁切线接触导致 non-manifold 的 bug
    (SCREW_POST_D 5.0 -> 4.0)
    文件:
    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
    [bottom.3mf, bottom.step, bottom.stl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]
2026-05-25 case_v5: 修复压力传感器固定 + FPC 排线槽
    压力传感器 (right +X side):
    - 旧: 整个 PCB 暴露为 3.6×3.6 方孔穿透壁
    - 新: 内壁 PCB 凹槽 (13×10.2×1.8mm) + 外壁单独 ⌀3.6 圆孔
    ── PCB 嵌入凹槽固定, 仅传感器圆顶 (PCB 右上角) 通过圆孔接触水
    ── 凹槽周向 0.3mm 装配间隙
    ── 传感器孔偏移 PCB 中心 (3, 3)mm 对应右上角
    FPC 排线避让 (top cover):
    - 旧: 1.7×73.9mm × 深 1mm 凹槽 (位置太浅, 视觉不显)
    - 新: PCB pocket 一侧凸出 1.7×35mm × 深 3mm 凹槽
    ── 比 PCB pocket 深 1.5mm
    ── 长 35mm (覆盖排线连接器宽度)
    ── 位置在 pocket 边缘外 0.2mm (明显切口)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
    [bottom.3mf, bottom.step, bottom.stl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]
2026-05-25 case_v5: FPC 排线槽改到 PCB 短边 (上下端方向)
    修复用户反馈:
    - 旧: FPC 凹槽沿 PCB 长边 (X 方向侧面) 1.7×35mm 深 3mm
    - 新: FPC 凹槽沿 PCB 短边 (Y 方向一端 -Y) 整宽×7mm 深 2.8mm
    理由: 屏幕显示区 60.6mm 在 PCB 73.5mm 上居中, 上下各 6.45mm 余量.
    其中一端 (默认 -Y 底端) 装 FPC 连接器/SPI 排线/元件,
    需要在 pocket 该端整宽加深 1.3mm 让元件凸入凹槽.
    参数化:
    - PCB_FLEX_DEPTH = 1.3 (加深量)
    - PCB_FLEX_END = -1 (-1 = -Y 底端, +1 = +Y 顶端)
    - PCB_FLEX_REGION_H = 7.0 (Y 方向覆盖)
    验证:
    - top: 2088 verts, 4192 faces, 4.25 cm³, watertight=yes ✓
    [top.3mf, top.step, top.stl]
2026-05-25 case_v5: FPC 槽精确化 + 压力传感器移底盖
    FPC / 元件让位槽 (top):
    - 旧: 整宽 (45.4mm) × 7mm × 深 2.8mm
    - 新: 22 × 5 × 深 1.3mm (居中 X, PCB 短边一端中央)
    ── 用户实测 PCB 元件区域
    压力传感器 (bottom):
    - 旧: 在 +X 长侧面内壁
    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
    [bottom.3mf, bottom.step, bottom.stl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]
2026-05-25 case_v5: 压力传感器调整: 侧面居中 + 凹槽放大 + 圆孔留边距
    位置:
    - 旧: 底面 (Z=0) 电池上方 (0, 33.5)
    - 新: +X 长侧面居中 (Y=0, Z=BOT_THICK/2)
    凹槽:
    - 间隙: 0.3 → 1.0mm (单边 0.5mm 装配松量)
    - 凹槽尺寸: 11.2×13.3 → 11.2×14.0 mm (沿 Y×Z)
    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
    [bottom.3mf, bottom.step, bottom.stl]
2026-05-25 case_v5: 加防水凹凸契合密封结构
    设计:
    - 下底顶面: U 形凹槽一圈 (宽 3mm × 深 2mm)
    距外壁 2mm 内退, 周长 ~270mm
    - 上盖底面: 对应位置凸起 lip (宽 2mm × 高 1.5mm)
    比凹槽窄 0.5mm 留装配松量 (单边 0.25mm)
    比凹槽浅 0.5mm 留 O 圈压缩量
    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
    [bottom.3mf, bottom.step, bottom.stl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]
2026-05-25 case_v5: 按钮 Z 居中 + 无线充电凹槽替代 USB-C
    按钮位置:
    - 旧 btn_z = BOT_THICK - 8.0 = 32.9mm (距顶端 8mm, 靠上)
    - 新 btn_z = BOT_THICK / 2 = 20.45mm (居中, 便于按帽对齐)
    充电方式改无线:
    - 删除 -Y 端 USB-C 矩形孔 (9.5×4.5mm)
    - 加圆形凹槽: 外底面居中 ⌀45mm, 深 1.3mm
    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
    [bottom.3mf, bottom.step, bottom.stl]
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2026-05-25 case_v5: 颠倒密封 - 凸起 lip 改到 bottom 顶面 / 凹槽改到 top 底面
    [bottom.3mf, bottom.step, bottom.stl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]
2026-05-25 case_v5: 修 top 被切成三块的 bug
    根因分析:
    - PCB pocket 45.4×73.9 比 U 槽内缘 43×71.5 大 1.2mm/侧
    - 在 PCB pocket 内但 U 槽内缘外的窄带 (X∈[21.5,22.7] 等):
    * z=[0,2] 被 U 槽环 (深 2mm) 切空
    * z=[2,3.5] 被 PCB pocket (从顶面起 1.5mm) 切空
    * 整个 z=[0,3.5] 全部挖空 → 顶层环被切断
    - 结果: 顶盖被切成 3 块: 外圈环 + 中央 Y 两端两条孤立小块
    - 外壳加大: PCB 周边间隙 1.5 → 4.0mm
    - CASE_W: 53 → 58
    - CASE_H: 81.5 → 86.5
    - U 槽内缘 (CASE - 2*SEAL_INSET - 2*SEAL_GROOVE_W): 47×75.5 > PCB pocket 45.4×73.9
    - 留 0.8mm 余量
    - top: 1 块, 58×86.5×3.5, watertight ✓
    - bottom: 1 块,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
    [bottom.3mf, bottom.step, bottom.stl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]
2026-05-25 case_v5: 颠倒密封 + 按钮上移 + 加表带耳
    密封 (再次颠倒回最初):
    - top 底面: 凸起 lip 朝下 (2×1.5mm)
    - bottom 顶面: U 形凹槽 (3×2mm) 装 ⌀2mm O 圈
    - 装配: top lip 卡入 bottom 凹槽压紧 O 圈
    按钮 Z 位置:
    - 旧 btn_z = BOT_THICK/2 = 20.45mm (居中)
    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
    [bottom.3mf, bottom.step, bottom.stl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]
2026-05-25 case_v5: top 加厚 3.5→5.0mm 防穿层
    问题: 之前 TOP_THICK=3.5 时, 顶面挖空特征 + 底面凸起 lip 太接近, 几何上 lip 根部容易被穿透
    - FPC 槽深 2.8 (从顶) → 底面剩 0.7mm
    - PCB pocket 深 1.5 → 底面剩 2.0mm
    - lip 高 1.5 在底面下方
    - 几何 boolean 容易出问题
    - TOP_THICK 3.5 → 5.0mm (加厚 1.5mm)
    - FPC 槽底面距 top 底 → 2.2mm (安全)
    - PCB pocket 底面距 top 底 → 3.5mm (充裕)
    - lip 仍在背面 z=[-1.5, 0] 朝下凸出
    - BOT_THICK 自动 = 44.4-5.0 = 39.4 (CASE_Z 总厚不变)
    最终:
    - top: 单块, 58×86.5×6.5 (含 1.5mm lip 凸出), watertight ✓
    - bottom: 单块, 58×98.5×39.4, watertight ✓
    - 装配总厚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
    [bottom.3mf, bottom.step, bottom.stl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]
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2026-05-25 v4 OTA 紧急修复: 删除自定义分区表 (设备 4MB Flash 不是 8MB)
    问题:
    - 烧录后 boot loop, 串口报错:
    E flash_parts: partition app1 offset 0x310000+0x300000 exceeds 0x400000
    - 实测 ESP32-S3-Nano 是 4MB Flash (不是预设的 8MB)
    - 自定义 partitions.csv (3MB×2 + 2MB SPIFFS = 8MB) 超容量
    - 删除 partitions.csv 回到 huge_app 单 APP 分区
    - 救援检测从 setup 最早期推到屏幕初始化之后 (白屏时能看到 BOOT 日志)
    - tft.init 后加 80ms delay 等 controller ready
    - 加详细 Serial 日志 [BOOT] 每步
    OTA 受限:
    - huge_app 是单 APP 分区, ArduinoOTA WiFi 推固件无法工作 (无第二 slot)
    - BLE 仍可启动 (长按 MODE+UP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
    [DiveWatch_v4.ino, ota_ble.ino]
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2026-05-25 HUD 综合优化: 分隔线加粗+水下清晰
    - 所有分隔线 1px → 2px (水下镜面/雾化下更易识别)
    顶/主区/速度条/数据条/底栏 横线, 主区竖线, 数据条 4 列竖线
    - 左半 大字深度: 移除重复的 NDL/TTS (右半默认状态已展示)
    改为 顶 "深度" 标签 + 大字 + "米" + 底 "▼最深 X.Xm" 强化 KPI
    - 速度条单位: m/m → m/min (更明确)
    - 速度数值低 warn 自动红色 (>g_ascentLimit 或 >g_descentLimit)
    - 数据条温度 <15°C 蓝色 (低温提示)
    - 数据条 fillRect/y 坐标重排不撞加粗分隔线
    - drawAscentBar fillRect 范围收紧 1px 不擦底分隔
    - 去掉 goto skip_status, 改 if 块
    [DiveWatch_v4.ino]
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2026-05-26 case_v5: 外壳总厚 22→26mm (容量+) 按钮/传感器上移
    - CASE_Z 22 → 26 (BOT_THICK 17 → 21, 内腔 ≈18.5mm 装电池+无线充线圈)
    - btn_z: BOT_THICK/2-1 (=7.5) → BOT_THICK-5 (=16) 上移到 PCB 板载按钮高度
    - press_cz 跟随 btn_z (内代码无需改, 引用同变量)
    - LUG_Z_CENTER: 8.5 → 10.5 居中到新 BOT_THICK
    - case_v5.py 加导出: step/stl/3mf 自动写 ../case/, 用 bambu-3mf skill 转兼容 3MF
    [bottom_case.3mf, bottom_case.step, bottom_case.stl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]
2026-05-26 case_v5: 按钮+传感器 Z 居中 + 按钮间距 13.1→12.6
    - btn_z: BOT_THICK-5 (=16, 偏顶) → BOT_THICK/2 (=10.5, 居中)
    - press_cz 跟随 btn_z 居中
    - BTN_SPACING 13.1 → 12.6 (-0.5mm, 最右按钮更靠中)
    [bottom_case.3mf, bottom_case.step, bottom_case.stl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]
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2026-05-27 case_v5: 加 TPU 保护套 (63×91.5×31, 单边 2.5mm 厚, 弹性 0.3mm 间隙套入)
    包裹整个 case_v5 主体并开:
    - 顶面: 屏幕窗 (SCREEN + 2mm 边距, 圆角)
    - 底面: 无线充电窗 ⌀ 47mm (大于 coil OD)
    - -X 侧: 3 按钮圆孔 ⌀ 5.5
    - +X 侧: 1 传感器圆孔 ⌀ 4.6
    - ±Y 端: 完全开口让表带耳 + 表带穿出 (Apple Watch 风格)
    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
    [bottom_case.3mf, top_cover.3mf, tpu_bumper.3mf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]
2026-05-31 top_cover 加厚 5→7mm + 屏幕窗 2 阶 lip 卡住屏幕
    - CASE_Z 26 → 28 (+2 总厚, BOT_THICK 不变=21)
    - TOP_THICK 5 → 7
    - 屏幕窗 两阶设计:
    · 顶层 z=6..7 (1mm): 41×57.6 (SCREEN - 2×LIP_W=1.5) 露屏区, 形成卡屏 lip
    · 下层 z=0..6 (6mm): 44.6×61.2 (SCREEN + FIT=0.6) 屏幕装入腔
    - 屏幕从底部装入到 lip 处卡住, 不会从顶面掉出
    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
    [top_cover.3mf, top_cover.step, top_cover.stl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]
2026-05-31 top_cover 独立加高到 7mm + 修屏幕 lip 被 PCB 沉槽挖穿的 bug
    bottom 零改动 (已树脂固化): BOT_THICK 仍 21, 几何/密封槽/螺丝孔位不变
    仅 top 高度 + 屏幕装入结构调整:
    - 屏幕窗改单一两层结构:
    · 顶层 lip (z=6..7, 1mm): 露屏 41×57.6, 单边卡屏 1.5mm, 屏幕朝顶不掉
    · 下层 PCB 模组腔 (z=0..6, 6mm): 贯穿底面装入 45.4×73.9
    - 删除原独立 PCB 沉槽 (45.4×73.9 延伸到 z=7, 会把 lip 环挖穿 → lip 失效)
    及冗余 FPC 让位槽 (6mm 贯穿腔已足够排线空间)
    - 内部余量: 腔 6mm - 模组 ~2.8mm = ~3mm 空间
    截面验证: z=6.5 实体 1748.7mm² > z=3.0 实体 1148.7mm² → lip 环确认保留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
    [top_cover.3mf, top_cover.step, top_cover.stl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]
2026-05-31 top_cover 9mm + 4 凸起卡屏 + 总厚 30 (装配 +2)
    仅改 top, bottom 不变 (已树脂固化):
    - CASE_Z 28→30, TOP_THICK 7→9 (+2 装配空间), BOT_THICK 21 不变
    - 屏幕窗腔内壁 4 边中点各加 1 个小凸起:
    3×0.8×2mm, 紧贴 lip 下方, 向内突出 0.8mm
    屏幕装入时轻推过凸起, 卡入后被锁住不晃
    - lip 仍保留 (顶层 1mm 缩口防上掉)
    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
    [top_cover.3mf, top_cover.step, top_cover.stl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]
2026-05-31 top_cover 回到 7mm (参考版 5+2) + 4 凸起卡屏
    参考 case_v5/top.3mf (58×86.5×5), 仅加高 2mm 到 7mm:
    - CASE_Z 30→28, TOP_THICK 9→7
    - BOT_THICK 不变 = 21 (已树脂固化)
    - 保留 lip (顶层 1mm, 41×57.6 露屏)
    - 保留 4 个凸起 (3×0.8×2mm, ±X/±Y 腔壁中点)
    紧贴 lip 下方 z=4..6, 卡住屏幕边框
    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
    [top_cover.3mf, top_cover.step, top_cover.stl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]
2026-05-31 top_cover 还原正确结构 + 加高 2mm + 4 凸起 + FPC 槽
    还原参考版 (top.3mf 5mm) 的正确层次, 仅加高 2mm:
    1. 屏幕窗 (贯穿 z=0..7): SCREEN 44×60.6, 显示面朝外
    2. PCB 沉槽 (装配面挖 1.5mm): PCB+0.4 = 45.4×73.9
    PCB 比屏幕宽 → 天然台阶 0.7mm/边 托住屏幕
    3. FPC 排线槽 (比沉槽再深 2.5mm): 22×5 在 PCB -Y 端
    4. 密封 U 槽 + 螺丝孔 (不变)
    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
    [top_cover.3mf, top_cover.step, top_cover.stl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]
2026-05-31 top_cover: 凸起移到 PCB 台阶 + 屏幕深度不变 + 装配面加 2mm
    屏幕相关深度与参考版 5mm 完全一致 (距显示面 z=0 不变):
    - PCB 台阶: z=3.5 (参考版 5-1.5=3.5, 新版 7-1.5-2=3.5)
    - FPC 排线槽底: z=1.0 (参考版 5-4=1, 新版 7-4-2=1)
    - 屏幕窗: 贯穿 44×60.6
    多出 2mm 在装配面一侧 (z=5..7):
    - PCB 沉槽挖穿到装配面 (3.5mm 深, 含 2mm 装配余量)
    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
    [top_cover.3mf, top_cover.step, top_cover.stl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]
2026-05-31 top: 凸起上移到 z=4.3 (台阶 3.5 + PCB 0.6 + 间隙 0.2), 压住 PCB 顶面
    [top_cover.3mf, top_cover.step, top_cover.stl]
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2026-06-03 fix(tpu): ±Y 表带开口对准耳片高度 + 两端对称
    原 bug:
    - 用 Plane.XZ sketch, 矩形中心落世界 z=0, 开口偏到 bumper 底部
    没对准耳片 (耳片中心 z=13), 实际只切到底部薄层
    - XZ 平面法线方向歧义, extrude 一端切入实体一端切向体外
    → 只有单端开口成功
    - 改用 XY 平面 sketch + 显式 Z 偏移 (open_z_lo..hi)
    - 开口对准耳片中心 z = TPU_OUT + LUG_Z_CENTER = 13
    - 高度覆盖 LUG_HEIGHT 8mm + 上下各 2mm 余量
    - Y 方向从内腔壁挖穿到外表面
    - 两端 sy=±1 对称
    截面验证: +Y/-Y 端壁沿 X 扫描完全对称
    |x|<14 开口 (表带 28mm 宽穿出), |x|>16 保留墙体
    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
    [tpu_bumper.3mf, tpu_bumper.step, tpu_bumper.stl]
